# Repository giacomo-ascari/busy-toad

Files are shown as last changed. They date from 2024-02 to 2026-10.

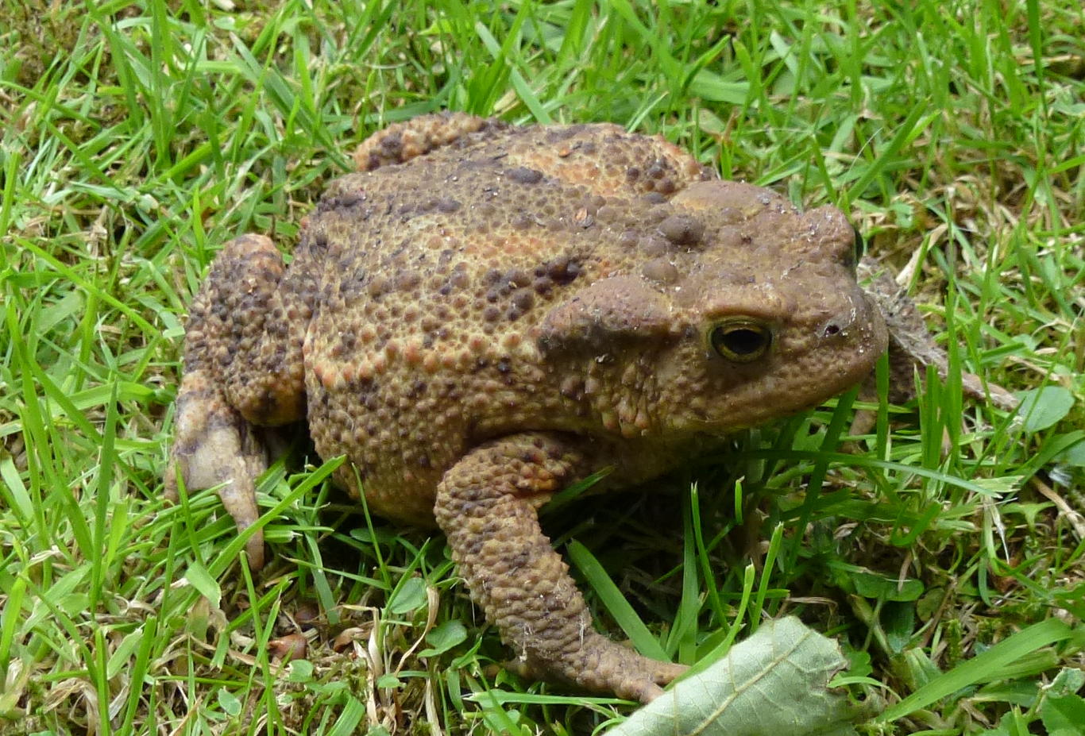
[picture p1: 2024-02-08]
images/ref.jpg

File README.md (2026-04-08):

# busy-toad

## Intro

Evolution of the digital pedal geekyToad. This page is a list of features/hardware that I would like to implement.

## System

### I/O

- Two audio instr/line inputs as TRS Jack (differential or single-ended)
- Two audio instr/line outputs as TRS Jack (differential or single-ended)
- One stereo output for headphones, hardwired to the two outputs
- OLED display, power LED, some non-assigned (yet) LEDs
- A lot of buttons and One rotary encoder with push buttono
- Volume knob for heaphones
- Four analog inputs as TRS Jack (e.g. expression pedals and stomp buttons)
- USB C device for power and FS data transfer

### Features

- Effect chains
- Programmable expression inputs as dynamic controls of effects
- Drum machine (synth + samples)
- Chromatic tuner
- Mixing matrix for effect chains and drum machine
- Simple cab emulation

## Hardware

### DSP MCU - STM32H750VBT6

- LQFP100 14x14x1.4mm
- ARM Cortex-M7, 480MHz, FPU, 128kB flash, 1024kB RAM
- Gotta use the CMSIS-DSP library!!!
- [mouser link](https://www.mouser.dk/ProductDetail/STMicroelectronics/STM32H750VBT6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)

### UI MCU - STM32H523CEU6

- UFQFPN-48
- ARM Cortex M33, 250MHz, FPU, 512kB flash, 272kB RAM
- [mouser link](https://eu.mouser.com/ProductDetail/STMicroelectronics/STM32H523CEU6?qs=ZcfC38r4Pot%2FWfU8ati%252BDA%3D%3D)

### CODEC - ADAU1916

- [analog devices link](https://www.analog.com/media/en/technical-documentation/data-sheets/adau1961.pdf)

Honorable mentions:

- cs4272, [cirrus logic link](https://www.cirrus.com/products/cs4272/), used in some focusrite scarlet interfaces [apparently](https://khronscave.blogspot.com/2019/10/55-focusrite-scarlett-2i2-teardown.html)
- E.D.'s favorite: tlv320aic3104-21
- daisy seed's: pcm3060 [ti link](https://www.ti.com/product/PCM3060#features)
- PCM1863 [ti link](https://www.ti.com/product/PCM1863) 

### FLASH - W25Q512JV

- w25q512jveim (still on the table!)
- the quad spi interface with the mcu needs a lot of pins :/

### DISPLAY - 3.83" OLED

- 3.83" OLED module, 320x132, 4-wire SPI, 16 level grayscale
- looks really interesting and promising, especially for the grayscale control (could have controllable brightness and such)
- framerate unknow, but still probably better than normal lcd displays
- [buydisplay link](https://www.buydisplay.com/catalog/product/view/id/1847/s/arduino-raspberry-pi-3-83-inch-oled-module-320x132-spi-16-level-grayscale/)
- ALTERNATIVE: ILI9341 SPI LCD display (the usual basically)

## Various notes

- probably not using this case: [1590XX](https://www.mouser.dk/ProductDetail/Hammond-Manufacturing/1590XXPR?qs=kWu6FN6bAPyKJolG0UKSGg%3D%3D)
- STM32 Cube IDE because yes.
- Debugging is done with cortex 4-wire-jtag/swd 10 pin connection.
- For the Eq: Linkwitz–Riley filters
- Denoising for 5v: either LDOs, or a lot of filtering (pi filter and ferrite beads like BLM21PG102SH1D)
- circuitry for codec I/O:
  - INA116: instrumentation amplifier with extremely low input bias
  - INA105 and 106: differential amplifiers with unit and fixed gain
  - INA1620: beast, dual differential signals amp
  - INA321 and 2321: instrumentation amplifiers, also dual channel
  - MCP6001/1R/1U/2/4: low power opamp used in gt
  - Quad Analog Switch/ Multiplexer/Demultiplexer MC74HC4066A
- For the switching circuitry (might not be needed with ADAU1961!)
  - MC74HC4066A (same as the focusrite, but apparently a little bit noisy)
  - TS5A3157
  - DG409 / DG410
  - MAX4617 (chatgpt likes this)
  - ADG736 (I like this one!) / ADG734 / ADG1606
  - TS5A3157
  - MAX14689
- Notes for capacitors
  - 20% is tolerable for PDB, but 10% is better
  - DC rating at least double the maximum applied voltage
  - increase cap value to account for derating and tolerance
  - for audio, avoid class 2 ceramics in signal path.
  - use NP0/C0G insted, unfortunately only available as small value caps (10nF or less)
- Available in lab
  - CA3140 (opamp)
  - MCP6294 (quad opamp)
  - MCP602 (dual op amp)
  - LM358 (dual op amp)
  - LM386N (audio amp)
  - AD623ANZ (opamp dif amp)
  - AD620ANZ (opamp dif amp)
- Expression pedals are hard man [...](https://missionengineering.com/understanding-expression-pedals/)
- I'm extremely dubious about the feasibility of the 48v phantom power for condenser microphones. A solution can be just buying an external mic pre-amp.
- [cool colors, i like them](https://coolors.co/30bced-303036-fffaff-fc5130-050401)
- [Differences-between-Mic-Line-and-Instrument-level](https://support.focusrite.com/hc/en-gb/articles/115004171025-Differences-between-Mic-Line-and-Instrument-level)

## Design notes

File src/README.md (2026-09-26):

# Source code

## Organization

The development relies on a CubeMX + cmake toolchain. The code for the primary MCU is `bt_h750`, while the secondary's one is found in `bt_h523`.

## How to stuff

### Flash #1

After having built the `.elf` file all is left to do is to flash it.

On terminal 1:

- `st-info --probe` giusto per vedere se legge la roba
- `st-util` per lanciare partire il server gdb. importante!

On terminal 2:

- `gdb-multiarch PATH_TO_ELF`
- `(gdb) target extended-remote localhost:4242`
- `(gdb) load`
- `(gdb) continue`

### Flash #2

`STM32_Programmer_CLI -c port=SWD mode=UR reset=HWrst -w build/Debug/bt_h750.elf -v -rst`

### Flash #3

Trust VSCode.

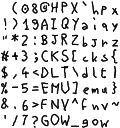
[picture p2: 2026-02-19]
images/font/raw_font_10x16.png

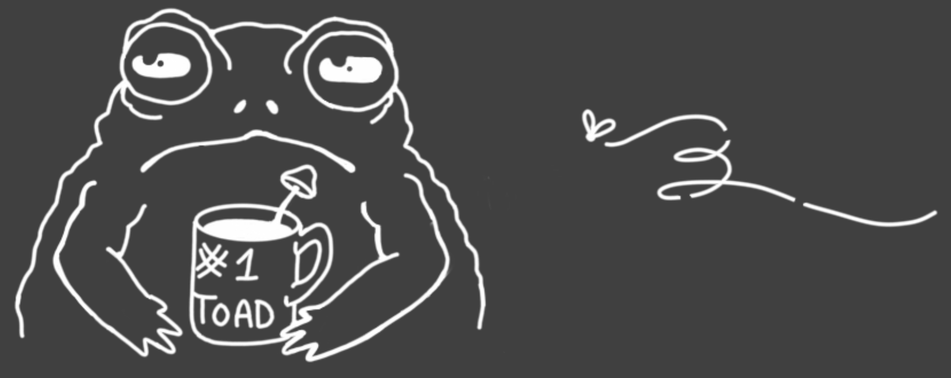
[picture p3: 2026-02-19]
images/toadddd.png

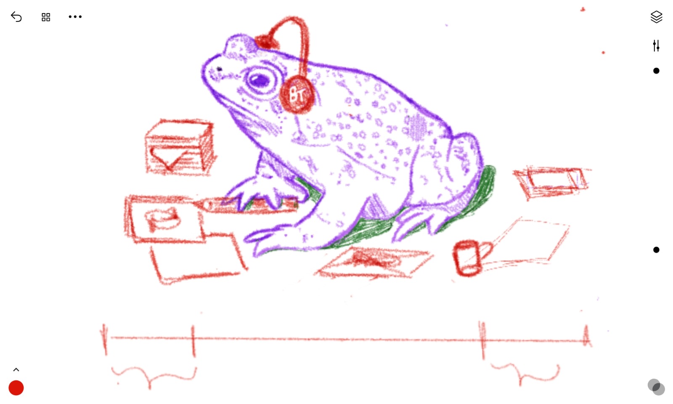
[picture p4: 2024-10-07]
images/g.jpg

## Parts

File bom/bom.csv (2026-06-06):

Reference | Qty | Value | Exclude from BOM | Footprint | Description
C1,C3,C5,C7,C12 | 5 | 100n |  | Capacitor_SMD:C_0603_1608Metric_Pad1.08x0.95mm_HandSolder | POWERSUPPLY
C2,C4,C6,C11 | 4 | 10u |  | Capacitor_SMD:C_0805_2012Metric_Pad1.18x1.45mm_HandSolder | POWERSUPPLY
C8,C13 | 2 | 1u |  | Capacitor_SMD:C_0603_1608Metric_Pad1.08x0.95mm_HandSolder | POWERSUPPLY
C9,C53,C58,C67,C69,C71,C72 | 7 | 2.2u |  | Capacitor_SMD:C_0603_1608Metric_Pad1.08x0.95mm_HandSolder | DPD
C10,C43,C44,C46,C47,C48,C49,C50,C51,C52,C54,C55,C56,C57,C59,C60,C61,C62,C64,C66,C68,C70 | 22 | 100n |  | Capacitor_SMD:C_0603_1608Metric_Pad1.08x0.95mm_HandSolder | DPD
C14 | 1 | 2.2u |  | Capacitor_SMD:C_0603_1608Metric_Pad1.08x0.95mm_HandSolder | APD
C15,C19,C22,C23,C24,C33,C34,C36,C39,C41,C80,C88 | 12 | 100n |  | Capacitor_SMD:C_0603_1608Metric_Pad1.08x0.95mm_HandSolder | APD
C16,C18,C20,C21 | 4 | 22u |  | Capacitor_SMD:C_0805_2012Metric_Pad1.18x1.45mm_HandSolder | APD
C17,C26,C27,C29,C30,C31,C79,C87 | 8 | 10u |  | Capacitor_SMD:C_0805_2012Metric_Pad1.18x1.45mm_HandSolder | APD
C25,C28,C32,C35,C37,C38,C40,C42 | 8 | 1u |  | Capacitor_SMD:C_0603_1608Metric_Pad1.08x0.95mm_HandSolder | APD
C45 | 1 | 10u |  | Capacitor_SMD:C_0805_2012Metric_Pad1.18x1.45mm_HandSolder | DPD
C63,C65 | 2 | 1u |  | Capacitor_SMD:C_0603_1608Metric_Pad1.08x0.95mm_HandSolder | DPD
C73,C76,C78,C83,C85,C90,C93,C96 | 8 | 470p |  | Capacitor_SMD:C_0603_1608Metric_Pad1.08x0.95mm_HandSolder | AUDIO
C74,C77,C81,C84,C86,C92,C94,C98 | 8 | 10u |  | Capacitor_SMD:C_0805_2012Metric_Pad1.18x1.45mm_HandSolder | AUDIO
C75,C82,C89,C95 | 4 | 2.7n |  | Capacitor_SMD:C_0603_1608Metric_Pad1.08x0.95mm_HandSolder | AUDIO
C91,C97 | 2 | 10n |  | Capacitor_SMD:C_0603_1608Metric_Pad1.08x0.95mm_HandSolder | AUDIO
D1,D2 | 2 | B5819W |  | library:SOD3716X125N | 40V 1A 600mV @ 1A SOD-123 Schottky Barrier Diodes (SBD)
D3,D5,D7,D9,D11,D13,D15,D17,D18 | 9 | LED |  | LED_SMD:LED_0603_1608Metric_Pad1.05x0.95mm_HandSolder | Light emitting diode
D4,D6,D8,D10,D12,D14,D16 | 7 | LED |  | LED_THT:LED_D3.0mm | Light emitting diode
IC1 | 1 | LV3842XDBVR |  | library:SOT95P280X145-6N | Switching Voltage Regulators 4-V to 36-V, 600-mA synchronous step-down converter 6-SOT-23 -40 to 125
IC2 | 1 | CS4282P |  | library:QFN40P600X600X80-49N-D | High performance two-channel codec Differential analog architecture High-resolution 32-bit digital architecture Low-latency digital filters and digital volume control Current-mode output for optimal dynamic range into application-specific output buffer PLL supports range of external system-clock references Sample timing alignment across multiple devices Synchronized control of external preamplifier gain Audio serial port (ASP) sample rates up to 768 kHz I2S, left-justified, and TDM data f
IC3 | 1 | TAD5242IRGER |  | library:TAD5242IRGER | Audio D/A Converter ICs Hardware-control stereo audio DAC with 120dB dynamic range, and headphone and line driver
IC4 | 1 | STM32H750VBT6 |  | library:QFP50P1600X1600X160-100N
IC5 | 1 | STM32H523CET6 |  | library:QFP50P900X900X160-48N | Arm Cortex-M33 32-bit MCU + TrustZone + FPU, 375 DMIPS, 250 MHz, 512-Kbyte flash, 272-Kbyte RAM
J2 | 1 | Barrel_Jack_Switch |  | library:694106301002_1 | DC Barrel Jack with an internal switch
J7 | 1 | USB_C_Receptacle_USB2.0_16P |  | Connector_USB:USB_C_Receptacle_GCT_USB4105-xx-A_16P_TopMnt_Horizontal | USB 2.0-only 16P Type-C Receptacle connector
J14 | 1 | Micro_SD_Card_Det2 |  | Connector_Card:microSD_HC_Molex_104031-0811 | Micro SD Card Socket with two card detection pins
J15,J16,J17,J18 | 4 | ReanNYS216G |  | library:NYS-216G
L1 | 1 | 18uH 1.5A |  | library:SRR6040A180M | Inductor with iron core
R1 | 1 | 100k |  | Resistor_SMD:R_0603_1608Metric_Pad0.98x0.95mm_HandSolder | Resistor
R2,R3 | 2 | 47k |  | Resistor_SMD:R_0603_1608Metric_Pad0.98x0.95mm_HandSolder | Resistor
R4,R5 | 2 | 22 |  | Resistor_SMD:R_0603_1608Metric_Pad0.98x0.95mm_HandSolder
R6,R10,R11,R12,R13,R14,R15,R16,R24,R25,R26,R27,R28,R29,R30,R31,R32,R33,R34,R35,R36,R37,R40,R44,R46,R52,R54,R59,R61,R65,R67 | 31 | 10k |  | Resistor_SMD:R_0603_1608Metric_Pad0.98x0.95mm_HandSolder
R7 | 1 | 4k7 |  | Resistor_SMD:R_0603_1608Metric_Pad0.98x0.95mm_HandSolder
R8,R9 | 2 | 5k1 |  | Resistor_SMD:R_0603_1608Metric_Pad0.98x0.95mm_HandSolder
R17,R18,R19,R20,R21,R22,R23 | 7 | 680/510 |  | Resistor_SMD:R_0603_1608Metric_Pad0.98x0.95mm_HandSolder
R38,R39 | 2 | 680 |  | Resistor_SMD:R_0603_1608Metric_Pad0.98x0.95mm_HandSolder
R41,R45,R49,R53,R57,R60,R63,R66 | 8 | 634 |  | Resistor_SMD:R_0603_1608Metric_Pad0.98x0.95mm_HandSolder
R42,R47,R50,R55,R58,R62,R64,R68 | 8 | 91 |  | Resistor_SMD:R_0603_1608Metric_Pad0.98x0.95mm_HandSolder
R43,R48,R51,R56 | 4 | 470 |  | Resistor_SMD:R_0603_1608Metric_Pad0.98x0.95mm_HandSolder
RV1,RV2,RV3 | 3 | CG0402MLU-12G |  | library:VARC1005X41N | ESD Suppressors / TVS Diodes CHIP GUARD 12VOLT
RV4 | 1 | R_Potentiometer |  | Potentiometer_THT:Potentiometer_Alpha_RD901F-40-00D_Single_Vertical_CircularHoles | Potentiometer
SW1 | 1 | RotaryEncoder_Switch |  | Rotary_Encoder:RotaryEncoder_Alps_EC11E-Switch_Vertical_H20mm_CircularMountingHoles | Rotary encoder, dual channel, incremental quadrate outputs, with switch
SW2,SW3,SW4,SW5,SW6,SW7,SW8,SW9,SW10,SW11 | 10 | SW_Push |  | Button_Switch_THT:SW_TH_Tactile_Omron_B3F-102x
U1,U2 | 2 | TLV76133DCY |  | Package_TO_SOT_SMD:SOT-223-3_TabPin2 | 3.3V, 1A, Low Noise, High-PSRR LDO Regulator, 2.5V...16V input, SOT-223
U3,U4 | 2 | MCP6004 |  | Package_SO:TSSOP-14_4.4x5mm_P0.65mm

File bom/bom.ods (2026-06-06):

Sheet: bom_rev_A
Reference | Qty | Value | Footprint | Description
C1,C3,C5,C7,C12 | 5 | 100n | Capacitor_SMD:C_0603_1608Metric_Pad1.08x0.95mm_HandSolder | POWERSUPPLY
C2,C4,C6,C11 | 4 | 10u | Capacitor_SMD:C_0805_2012Metric_Pad1.18x1.45mm_HandSolder | POWERSUPPLY
C8,C13 | 2 | 1u | Capacitor_SMD:C_0603_1608Metric_Pad1.08x0.95mm_HandSolder | POWERSUPPLY
C9,C38,C42,C52,C54,C56 | 6 | 2.2u | Capacitor_SMD:C_0603_1608Metric_Pad1.08x0.95mm_HandSolder | DPD
C10,C22,C25,C28,C29,C31,C32,C33,C34,C35,C36,C37,C39,C40,C41,C43,C44,C45,C46,C47,C49,C51,C53,C55 | 24 | 100n | Capacitor_SMD:C_0603_1608Metric_Pad1.08x0.95mm_HandSolder | DPD
C14 | 1 | 2.2u | Capacitor_SMD:C_0603_1608Metric_Pad1.08x0.95mm_HandSolder | APD
C15,C18,C21,C65,C74 | 5 | 100n | Capacitor_SMD:C_0603_1608Metric_Pad1.08x0.95mm_HandSolder | APD
C16,C19,C64,C73 | 4 | 10u | Capacitor_SMD:C_0805_2012Metric_Pad1.18x1.45mm_HandSolder | APD
C17,C20 | 2 | 1u | Capacitor_SMD:C_0603_1608Metric_Pad1.08x0.95mm_HandSolder | APD
C23,C24,C30 | 3 | 10u | Capacitor_SMD:C_0805_2012Metric_Pad1.18x1.45mm_HandSolder | DPD
C26,C58,C62,C66,C70,C72,C78,C80,C84 | 9 | 10u | Capacitor_SMD:C_0805_2012Metric_Pad1.18x1.45mm_HandSolder | AUDIO
C27 | 1 | 100n | Capacitor_SMD:C_0603_1608Metric_Pad1.08x0.95mm_HandSolder | AUDIO
C48,C50 | 2 | 1u | Capacitor_SMD:C_0603_1608Metric_Pad1.08x0.95mm_HandSolder | DPD
C57,C61,C63,C69,C71,C76,C79,C82 | 8 | 470p | Capacitor_SMD:C_0603_1608Metric_Pad1.08x0.95mm_HandSolder | AUDIO
C59,C67,C75,C81 | 4 | 2.7n | Capacitor_SMD:C_0603_1608Metric_Pad1.08x0.95mm_HandSolder | AUDIO
C60,C68,C77,C83 | 4 | 10n | Capacitor_SMD:C_0603_1608Metric_Pad1.08x0.95mm_HandSolder | AUDIO
D1,D2 | 2 | B5819W | library:SOD3716X125N | 40V 1A 600mV @ 1A SOD-123 Schottky Barrier Diodes (SBD)
D3,D5,D7,D9,D11,D13,D15,D17,D18 | 9 | LED | LED_SMD:LED_0603_1608Metric_Pad1.05x0.95mm_HandSolder | Light emitting diode
D4,D6,D8,D10,D12,D14,D16 | 7 | LED | LED_THT:LED_D3.0mm | Light emitting diode
H1,H2,H3,H4,H5,H6 | 6 | MountingHole_Pad | MountingHole:MountingHole_3.2mm_M3_ISO14580_Pad | Mounting Hole with connection
IC1 | 1 | LV3842XDBVR | library:SOT95P280X145-6N | Switching Voltage Regulators 4-V to 36-V, 600-mA synchronous step-down converter 6-SOT-23 -40 to 125
IC2 | 1 | ADAU1961WBCPZ-R7 | library:QFN50P500X500X100-33N-D | General Purpose Audio Codec 2ADC / 2DAC Ch Automotive 32-Pin LFCSP EP T/R
IC3 | 1 | STM32H750VBT6 | library:QFP50P1600X1600X160-100N
IC4 | 1 | STM32H523CEU6 | library:QFN50P700X700X60-49N-D
IC5 | 1 | W25Q512JVEIM | library:SON127P800X600X80-9N-D
J1 | 1 | Conn_01x02 | Connector_PinHeader_2.54mm:PinHeader_1x02_P2.54mm_Vertical | Generic connector, single row, 01x02, script generated (kicad-library-utils/schlib/autogen/connector/)
J2 | 1 | Barrel_Jack_Switch | library:694106301002_1 | DC Barrel Jack with an internal switch
J3 | 1 | Conn_01x01 | Connector_PinHeader_2.54mm:PinHeader_1x01_P2.54mm_Vertical | Generic connector, single row, 01x01, script generated (kicad-library-utils/schlib/autogen/connector/)
J4,J5,J7,J9,J10,J11 | 6 | Conn_01x03 | Connector_JST:JST_PH_B3B-PH-K_1x03_P2.00mm_Vertical | Generic connector, single row, 01x03, script generated (kicad-library-utils/schlib/autogen/connector/)
J6 | 1 | ER-OLEDM0383-1-SPI_Conn_01x10 | library:ER-OLEDM0383-1-SPI | Generic connector, single row, 01x10, script generated (kicad-library-utils/schlib/autogen/connector/)
J8 | 1 | USB_C_Receptacle_USB2.0_16P | Connector_USB:USB_C_Receptacle_GCT_USB4105-xx-A_16P_TopMnt_Horizontal | USB 2.0-only 16P Type-C Receptacle connector
J12,J13,J14 | 3 | Conn_01x05 | Connector_JST:JST_PH_B5B-PH-K_1x05_P2.00mm_Vertical | Generic connector, single row, 01x05, script generated (kicad-library-utils/schlib/autogen/connector/)
J15,J16,J17,J18 | 4 | ReanNYS216G | library:NYS-216G
JP1 | 1 | SJ+ | Jumper:SolderJumper-3_P1.3mm_Open_Pad1.0x1.5mm | Solder Jumper, 3-pole, open
JP2 | 1 | SJ- | Jumper:SolderJumper-3_P1.3mm_Open_Pad1.0x1.5mm | Solder Jumper, 3-pole, open
L1 | 1 | 18uH 1.5A | library:SRR6040A180M | Inductor with iron core
R1 | 1 | 100k | Resistor_SMD:R_0603_1608Metric_Pad0.98x0.95mm_HandSolder | Resistor
R2,R3 | 2 | 47k | Resistor_SMD:R_0603_1608Metric_Pad0.98x0.95mm_HandSolder | Resistor
R4 | 1 | 49.9 | Resistor_SMD:R_0603_1608Metric_Pad0.98x0.95mm_HandSolder | Resistor
R5,R6,R7,R8 | 4 | 0 | Resistor_SMD:R_0603_1608Metric_Pad0.98x0.95mm_HandSolder | Resistor
R9,R11,R12,R15,R16,R17,R18,R19,R27,R28,R29,R30,R31,R32,R33,R34,R35,R36,R37,R38,R39,R40,R46,R48,R54,R56,R61,R63,R67,R69 | 30 | 10k | Resistor_SMD:R_0603_1608Metric_Pad0.98x0.95mm_HandSolder
R10 | 1 | 4k7 | Resistor_SMD:R_0603_1608Metric_Pad0.98x0.95mm_HandSolder
R13,R14 | 2 | 5k1 | Resistor_SMD:R_0603_1608Metric_Pad0.98x0.95mm_HandSolder
R20,R21,R22,R23,R24,R25,R26 | 7 | 680/510 | Resistor_SMD:R_0603_1608Metric_Pad0.98x0.95mm_HandSolder
R41,R42 | 2 | 680 | Resistor_SMD:R_0603_1608Metric_Pad0.98x0.95mm_HandSolder
R43,R47,R51,R55,R59,R62,R65,R68 | 8 | 634 | Resistor_SMD:R_0603_1608Metric_Pad0.98x0.95mm_HandSolder
R44,R49,R52,R57,R60,R64,R66,R70 | 8 | 91 | Resistor_SMD:R_0603_1608Metric_Pad0.98x0.95mm_HandSolder
R45,R50,R53,R58 | 4 | 470 | Resistor_SMD:R_0603_1608Metric_Pad0.98x0.95mm_HandSolder
RV1,RV2,RV3 | 3 | CG0402MLU-12G | library:VARC1005X41N | ESD Suppressors / TVS Diodes CHIP GUARD 12VOLT
RV4 | 1 | R_Potentiometer | Potentiometer_THT:Potentiometer_Alpha_RD901F-40-00D_Single_Vertical_CircularHoles
SW1 | 1 | RotaryEncoder_Switch | Rotary_Encoder:RotaryEncoder_Alps_EC11E-Switch_Vertical_H20mm_CircularMountingHoles | Rotary encoder, dual channel, incremental quadrate outputs, with switch
SW2,SW3,SW4,SW5,SW6,SW7,SW8,SW9,SW10,SW11 | 10 | SW_Push | Button_Switch_THT:SW_TH_Tactile_Omron_B3F-102x
TP1,TP2,TP3,TP4 | 4 | TestPoint | TestPoint:TestPoint_Pad_D1.0mm | test point
U1,U2 | 2 | TLV76133DCY | Package_TO_SOT_SMD:SOT-223-3_TabPin2 | 3.3V, 1A, Low Noise, High-PSRR LDO Regulator, 2.5V...16V input, SOT-223
U3,U4 | 2 | MCP6004 | Package_SO:TSSOP-14_4.4x5mm_P0.65mm

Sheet: bom_rev_B
Reference | Qty | Value | Footprint | Description
C1,C3,C5,C7,C12 | 5 | 100n | Capacitor_SMD:C_0603_1608Metric_Pad1.08x0.95mm_HandSolder | POWERSUPPLY
C2,C4,C6,C11 | 4 | 10u | Capacitor_SMD:C_0805_2012Metric_Pad1.18x1.45mm_HandSolder | POWERSUPPLY
C8,C15 | 2 | 1u | Capacitor_SMD:C_0603_1608Metric_Pad1.08x0.95mm_HandSolder | POWERSUPPLY
C9,C60,C65,C74,C76,C78,C79 | 7 | 2.2u | Capacitor_SMD:C_0603_1608Metric_Pad1.08x0.95mm_HandSolder | DPD
C10,C50,C51,C53,C54,C55,C56,C57,C58,C59,C61,C62,C63,C64,C66,C67,C68,C69,C71,C73,C75,C77 | 22 | 100n | Capacitor_SMD:C_0603_1608Metric_Pad1.08x0.95mm_HandSolder | DPD
C13,C14,C70,C72 | 4 | 1u | Capacitor_SMD:C_0603_1608Metric_Pad1.08x0.95mm_HandSolder | DPD
C16 | 1 | 2.2u | Capacitor_SMD:C_0603_1608Metric_Pad1.08x0.95mm_HandSolder | APD
C17,C22,C23,C25,C28,C29,C30,C38,C39,C47,C48,C88,C97 | 13 | 100n | Capacitor_SMD:C_0603_1608Metric_Pad1.08x0.95mm_HandSolder | APD
C18,C24,C26,C27 | 4 | 22u | Capacitor_SMD:C_0805_2012Metric_Pad1.18x1.45mm_HandSolder | APD
C19,C20,C31,C33,C34,C35,C37,C40,C41,C42,C46,C49 | 12 | 1u | Capacitor_SMD:C_0603_1608Metric_Pad1.08x0.95mm_HandSolder | APD
C21,C32,C36,C43,C87,C96 | 6 | 10u | Capacitor_SMD:C_0805_2012Metric_Pad1.18x1.45mm_HandSolder | APD
C44,C45 | 2 | 47u | Capacitor_SMD:C_0805_2012Metric_Pad1.18x1.45mm_HandSolder | APD
C52 | 1 | 10u | Capacitor_SMD:C_0805_2012Metric_Pad1.18x1.45mm_HandSolder | DPD
C80,C84,C86,C92,C94,C99,C102,C105 | 8 | 470p | Capacitor_SMD:C_0603_1608Metric_Pad1.08x0.95mm_HandSolder | AUDIO
C81,C85,C89,C93,C95,C101,C103,C107 | 8 | 10u | Capacitor_SMD:C_0805_2012Metric_Pad1.18x1.45mm_HandSolder | AUDIO
C82,C90,C98,C104 | 4 | 2.7n | Capacitor_SMD:C_0603_1608Metric_Pad1.08x0.95mm_HandSolder | AUDIO
C83,C91,C100,C106 | 4 | 10n | Capacitor_SMD:C_0603_1608Metric_Pad1.08x0.95mm_HandSolder | AUDIO
D1,D2 | 2 | B5819W | library:SOD3716X125N | 40V 1A 600mV @ 1A SOD-123 Schottky Barrier Diodes (SBD)
D3,D5,D7,D9,D11,D13,D15,D17,D18 | 9 | LED | LED_SMD:LED_0603_1608Metric_Pad1.05x0.95mm_HandSolder | Light emitting diode
D4,D6,D8,D10,D12,D14,D16 | 7 | LED | LED_THT:LED_D3.0mm | Light emitting diode
IC1 | 1 | LV3842XDBVR | library:SOT95P280X145-6N | Switching Voltage Regulators 4-V to 36-V, 600-mA synchronous step-down converter 6-SOT-23 -40 to 125
IC2 | 1 | TLV320DAC3203IRGER | library:QFN50P400X400X100-25N-D | Interface - CODECs Ultra Low Pwr Stereo Audio Codec
IC3 | 1 | CS4282P | library:QFN40P600X600X80-49N-D
IC4 | 1 | STM32H750VBT6 | library:QFP50P1600X1600X160-100N
IC5 | 1 | STM32H523CET6 | library:QFP50P900X900X160-48N | Arm Cortex-M33 32-bit MCU + TrustZone + FPU, 375 DMIPS, 250 MHz, 512-Kbyte flash, 272-Kbyte RAM
J2 | 1 | Barrel_Jack_Switch | library:694106301002_1 | DC Barrel Jack with an internal switch
J7 | 1 | USB_C_Receptacle_USB2.0_16P | Connector_USB:USB_C_Receptacle_GCT_USB4105-xx-A_16P_TopMnt_Horizontal | USB 2.0-only 16P Type-C Receptacle connector
J14 | 1 | Micro_SD_Card_Det2 | Connector_Card:microSD_HC_Molex_104031-0811 | Micro SD Card Socket with two card detection pins
J15,J16,J17,J18 | 4 | ReanNYS216G | library:NYS-216G
L1 | 1 | 18uH 1.5A | library:SRR6040A180M | Inductor with iron core
R1 | 1 | 100k | Resistor_SMD:R_0603_1608Metric_Pad0.98x0.95mm_HandSolder | Resistor
R2,R3 | 2 | 47k | Resistor_SMD:R_0603_1608Metric_Pad0.98x0.95mm_HandSolder | Resistor
R4,R8,R9,R10,R11,R12,R13,R14,R22,R23,R24,R25,R26,R27,R28,R29,R30,R31,R32,R33,R34,R35,R38,R42,R44,R50,R52,R57,R59,R63,R65 | 31 | 10k | Resistor_SMD:R_0603_1608Metric_Pad0.98x0.95mm_HandSolder
R5 | 1 | 4k7 | Resistor_SMD:R_0603_1608Metric_Pad0.98x0.95mm_HandSolder
R6,R7 | 2 | 5k1 | Resistor_SMD:R_0603_1608Metric_Pad0.98x0.95mm_HandSolder
R15,R16,R17,R18,R19,R20,R21 | 7 | 680/510 | Resistor_SMD:R_0603_1608Metric_Pad0.98x0.95mm_HandSolder
R36,R37 | 2 | 680 | Resistor_SMD:R_0603_1608Metric_Pad0.98x0.95mm_HandSolder
R39,R43,R47,R51,R55,R58,R61,R64 | 8 | 634 | Resistor_SMD:R_0603_1608Metric_Pad0.98x0.95mm_HandSolder
R40,R45,R48,R53,R56,R60,R62,R66 | 8 | 91 | Resistor_SMD:R_0603_1608Metric_Pad0.98x0.95mm_HandSolder
R41,R46,R49,R54 | 4 | 470 | Resistor_SMD:R_0603_1608Metric_Pad0.98x0.95mm_HandSolder
RV1,RV2,RV3 | 3 | CG0402MLU-12G | library:VARC1005X41N | ESD Suppressors / TVS Diodes CHIP GUARD 12VOLT
RV4 | 1 | R_Potentiometer | Potentiometer_THT:Potentiometer_Alpha_RD901F-40-00D_Single_Vertical_CircularHoles | Potentiometer
SW1 | 1 | RotaryEncoder_Switch | Rotary_Encoder:RotaryEncoder_Alps_EC11E-Switch_Vertical_H20mm_CircularMountingHoles | Rotary encoder, dual channel, incremental quadrate outputs, with switch
SW2,SW3,SW4,SW5,SW6,SW7,SW8,SW9,SW10,SW11 | 10 | SW_Push | Button_Switch_THT:SW_TH_Tactile_Omron_B3F-102x
U1,U3 | 2 | TLV76133DCY | Package_TO_SOT_SMD:SOT-223-3_TabPin2 | 3.3V, 1A, Low Noise, High-PSRR LDO Regulator, 2.5V...16V input, SOT-223
U2 | 1 | TPS7A2018PDBV | Package_TO_SOT_SMD:SOT-23-5 | 300 mA Low Dropout Voltage Regulator, Fixed Output, 1.6..6.0Vin, Low-Noise (7μV RMS), 6.5μA IQ LDO, SOT-23
U4,U5 | 2 | MCP6004 | Package_SO:TSSOP-14_4.4x5mm_P0.65mm

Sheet: bom_rev_B_2
Reference | Qty | Value | Footprint | Description
C1,C3,C5,C7,C12 | 5 | 100n | Capacitor_SMD:C_0603_1608Metric_Pad1.08x0.95mm_HandSolder | POWERSUPPLY
C2,C4,C6,C11 | 4 | 10u | Capacitor_SMD:C_0805_2012Metric_Pad1.18x1.45mm_HandSolder | POWERSUPPLY
C8,C13 | 2 | 1u | Capacitor_SMD:C_0603_1608Metric_Pad1.08x0.95mm_HandSolder | POWERSUPPLY
C9,C53,C58,C67,C69,C71,C72 | 7 | 2.2u | Capacitor_SMD:C_0603_1608Metric_Pad1.08x0.95mm_HandSolder | DPD
C10,C43,C44,C46,C47,C48,C49,C50,C51,C52,C54,C55,C56,C57,C59,C60,C61,C62,C64,C66,C68,C70 | 22 | 100n | Capacitor_SMD:C_0603_1608Metric_Pad1.08x0.95mm_HandSolder | DPD
C14 | 1 | 2.2u | Capacitor_SMD:C_0603_1608Metric_Pad1.08x0.95mm_HandSolder | APD
C15,C19,C22,C23,C24,C33,C34,C36,C39,C41,C80,C88 | 12 | 100n | Capacitor_SMD:C_0603_1608Metric_Pad1.08x0.95mm_HandSolder | APD
C16,C18,C20,C21 | 4 | 22u | Capacitor_SMD:C_0805_2012Metric_Pad1.18x1.45mm_HandSolder | APD
C17,C26,C27,C29,C30,C31,C79,C87 | 8 | 10u | Capacitor_SMD:C_0805_2012Metric_Pad1.18x1.45mm_HandSolder | APD
C25,C28,C32,C35,C37,C38,C40,C42 | 8 | 1u | Capacitor_SMD:C_0603_1608Metric_Pad1.08x0.95mm_HandSolder | APD
C45 | 1 | 10u | Capacitor_SMD:C_0805_2012Metric_Pad1.18x1.45mm_HandSolder | DPD
C63,C65 | 2 | 1u | Capacitor_SMD:C_0603_1608Metric_Pad1.08x0.95mm_HandSolder | DPD
C73,C76,C78,C83,C85,C90,C93,C96 | 8 | 470p | Capacitor_SMD:C_0603_1608Metric_Pad1.08x0.95mm_HandSolder | AUDIO
C74,C77,C81,C84,C86,C92,C94,C98 | 8 | 10u | Capacitor_SMD:C_0805_2012Metric_Pad1.18x1.45mm_HandSolder | AUDIO
C75,C82,C89,C95 | 4 | 2.7n | Capacitor_SMD:C_0603_1608Metric_Pad1.08x0.95mm_HandSolder | AUDIO
C91,C97 | 2 | 10n | Capacitor_SMD:C_0603_1608Metric_Pad1.08x0.95mm_HandSolder | AUDIO
D1,D2 | 2 | B5819W | library:SOD3716X125N | 40V 1A 600mV @ 1A SOD-123 Schottky Barrier Diodes (SBD)
D3,D5,D7,D9,D11,D13,D15,D17,D18 | 9 | LED | LED_SMD:LED_0603_1608Metric_Pad1.05x0.95mm_HandSolder | Light emitting diode
D4,D6,D8,D10,D12,D14,D16 | 7 | LED | LED_THT:LED_D3.0mm | Light emitting diode
IC1 | 1 | LV3842XDBVR | library:SOT95P280X145-6N | Switching Voltage Regulators 4-V to 36-V, 600-mA synchronous step-down converter 6-SOT-23 -40 to 125
IC2 | 1 | CS4282P | library:QFN40P600X600X80-49N-D | High performance two-channel codec Differential analog architecture High-resolution 32-bit digital architecture Low-latency digital filters and digital volume control Current-mode output for optimal dynamic range into application-specific output buffer PLL supports range of external system-clock references Sample timing alignment across multiple devices Synchronized control of external preamplifier gain Audio serial port (ASP) sample rates up to 768 kHz I2S, left-justified, and TDM data f
IC3 | 1 | TAD5242IRGER | library:TAD5242IRGER | Audio D/A Converter ICs Hardware-control stereo audio DAC with 120dB dynamic range, and headphone and line driver
IC4 | 1 | STM32H750VBT6 | library:QFP50P1600X1600X160-100N
IC5 | 1 | STM32H523CET6 | library:QFP50P900X900X160-48N | Arm Cortex-M33 32-bit MCU + TrustZone + FPU, 375 DMIPS, 250 MHz, 512-Kbyte flash, 272-Kbyte RAM
J2 | 1 | Barrel_Jack_Switch | library:694106301002_1 | DC Barrel Jack with an internal switch
J7 | 1 | USB_C_Receptacle_USB2.0_16P | Connector_USB:USB_C_Receptacle_GCT_USB4105-xx-A_16P_TopMnt_Horizontal | USB 2.0-only 16P Type-C Receptacle connector
J14 | 1 | Micro_SD_Card_Det2 | Connector_Card:microSD_HC_Molex_104031-0811 | Micro SD Card Socket with two card detection pins
J15,J16,J17,J18 | 4 | ReanNYS216G | library:NYS-216G
L1 | 1 | 18uH 1.5A | library:SRR6040A180M | Inductor with iron core
R1 | 1 | 100k | Resistor_SMD:R_0603_1608Metric_Pad0.98x0.95mm_HandSolder | Resistor
R2,R3 | 2 | 47k | Resistor_SMD:R_0603_1608Metric_Pad0.98x0.95mm_HandSolder | Resistor
R4,R5 | 2 | 22 | Resistor_SMD:R_0603_1608Metric_Pad0.98x0.95mm_HandSolder
R6,R10,R11,R12,R13,R14,R15,R16,R24,R25,R26,R27,R28,R29,R30,R31,R32,R33,R34,R35,R36,R37,R40,R44,R46,R52,R54,R59,R61,R65,R67 | 31 | 10k | Resistor_SMD:R_0603_1608Metric_Pad0.98x0.95mm_HandSolder
R7 | 1 | 4k7 | Resistor_SMD:R_0603_1608Metric_Pad0.98x0.95mm_HandSolder
R8,R9 | 2 | 5k1 | Resistor_SMD:R_0603_1608Metric_Pad0.98x0.95mm_HandSolder
R17,R18,R19,R20,R21,R22,R23 | 7 | 680/510 | Resistor_SMD:R_0603_1608Metric_Pad0.98x0.95mm_HandSolder
R38,R39 | 2 | 680 | Resistor_SMD:R_0603_1608Metric_Pad0.98x0.95mm_HandSolder
R41,R45,R49,R53,R57,R60,R63,R66 | 8 | 634 | Resistor_SMD:R_0603_1608Metric_Pad0.98x0.95mm_HandSolder
R42,R47,R50,R55,R58,R62,R64,R68 | 8 | 91 | Resistor_SMD:R_0603_1608Metric_Pad0.98x0.95mm_HandSolder
R43,R48,R51,R56 | 4 | 470 | Resistor_SMD:R_0603_1608Metric_Pad0.98x0.95mm_HandSolder
RV1,RV2,RV3 | 3 | CG0402MLU-12G | library:VARC1005X41N | ESD Suppressors / TVS Diodes CHIP GUARD 12VOLT
RV4 | 1 | R_Potentiometer | Potentiometer_THT:Potentiometer_Alpha_RD901F-40-00D_Single_Vertical_CircularHoles | Potentiometer
SW1 | 1 | RotaryEncoder_Switch | Rotary_Encoder:RotaryEncoder_Alps_EC11E-Switch_Vertical_H20mm_CircularMountingHoles | Rotary encoder, dual channel, incremental quadrate outputs, with switch
SW2,SW3,SW4,SW5,SW6,SW7,SW8,SW9,SW10,SW11 | 10 | SW_Push | Button_Switch_THT:SW_TH_Tactile_Omron_B3F-102x
U1,U2 | 2 | TLV76133DCY | Package_TO_SOT_SMD:SOT-223-3_TabPin2 | 3.3V, 1A, Low Noise, High-PSRR LDO Regulator, 2.5V...16V input, SOT-223
U3,U4 | 2 | MCP6004 | Package_SO:TSSOP-14_4.4x5mm_P0.65mm

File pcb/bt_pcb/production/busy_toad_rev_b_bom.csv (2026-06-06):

Designator | Footprint | Quantity | Value | LCSC Part #
C1, C10, C12, C15, C19, C22, C23, C24, C3, C33, C34, C36, C39, C41, C43, C44, C46, C47, C48, C49, C5, C50, C51, C52, C54, C55, C56, C57, C59, C60, C61, C62, C64, C66, C68, C7, C70, C80, C88 | 0603 | 39 | 100n
C11, C17, C2, C26, C27, C29, C30, C31, C4, C45, C6, C74, C77, C79, C81, C84, C86, C87, C92, C94, C98 | 0805 | 21 | 10u
C13, C25, C28, C32, C35, C37, C38, C40, C42, C63, C65, C8 | 0603 | 12 | 1u
C14, C53, C58, C67, C69, C71, C72, C9 | 0603 | 8 | 2.2u
C16, C18, C20, C21 | 0805 | 4 | 22u
C73, C76, C78, C83, C85, C90, C93, C96 | 0603 | 8 | 470p
C75, C82, C89, C95 | 0603 | 4 | 2.7n
C91, C97 | 0603 | 2 | 10n
D1, D2 | SOD3716X125N | 2 | B5819W
D10, D12, D14, D16, D4, D6, D8 | LED_D3.0mm | 7 | LED
D11, D13, D15, D17, D18, D3, D5, D7, D9 | 0603 | 9 | LED
IC1 | SOT95P280X145-6N | 1 | LV3842XDBVR
IC2 | QFN40P600X600X80-49N-D | 1 | CS4282P
IC3 | TAD5242IRGER | 1 | TAD5242IRGER
IC4 | QFP50P1600X1600X160-100N | 1 | STM32H750VBT6
IC5 | QFP50P900X900X160-48N | 1 | STM32H523CET6
J14 | microSD_HC_Molex_104031-0811 | 1 | Micro_SD_Card_Det2
J15, J16, J17, J18 | NYS-216G | 4 | ReanNYS216G
J2 | 694106301002_1 | 1 | Barrel_Jack_Switch
J7 | USB_C_Receptacle_GCT_USB4105-xx-A_16P_TopMnt_Horizontal | 1 | USB_C_Receptacle_USB2.0_16P
L1 | SRR6040A180M | 1 | 18uH 1.5A
R1 | 0603 | 1 | 100k
R10, R11, R12, R13, R14, R15, R16, R24, R25, R26, R27, R28, R29, R30, R31, R32, R33, R34, R35, R36, R37, R40, R44, R46, R52, R54, R59, R6, R61, R65, R67 | 0603 | 31 | 10k
R17, R18, R19, R20, R21, R22, R23 | 0603 | 7 | 680/510
R2, R3 | 0603 | 2 | 47k
R38, R39 | 0603 | 2 | 680
R4, R5 | 0603 | 2 | 22
R41, R45, R49, R53, R57, R60, R63, R66 | 0603 | 8 | 634
R42, R47, R50, R55, R58, R62, R64, R68 | 0603 | 8 | 91
R43, R48, R51, R56 | 0603 | 4 | 470
R7 | 0603 | 1 | 4k7
R8, R9 | 0603 | 2 | 5k1
RV1, RV2, RV3 | VARC1005X41N | 3 | CG0402MLU-12G
RV4 | Potentiometer_Alpha_RD901F-40-00D_Single_Vertical_CircularHoles | 1 | R_Potentiometer
SW1 | RotaryEncoder_Alps_EC11E-Switch_Vertical_H20mm_CircularMountingHoles | 1 | RotaryEncoder_Switch
SW10, SW11, SW2, SW3, SW4, SW5, SW6, SW7, SW8, SW9 | SW_TH_Tactile_Omron_B3F-102x | 10 | SW_Push
U1, U2 | SOT-223-3_TabPin2 | 2 | TLV76133DCY
U3, U4 | TSSOP-14_4.4x5mm_P0.65mm | 2 | MCP6004

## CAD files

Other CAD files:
cad/drafts/profile.FCStd

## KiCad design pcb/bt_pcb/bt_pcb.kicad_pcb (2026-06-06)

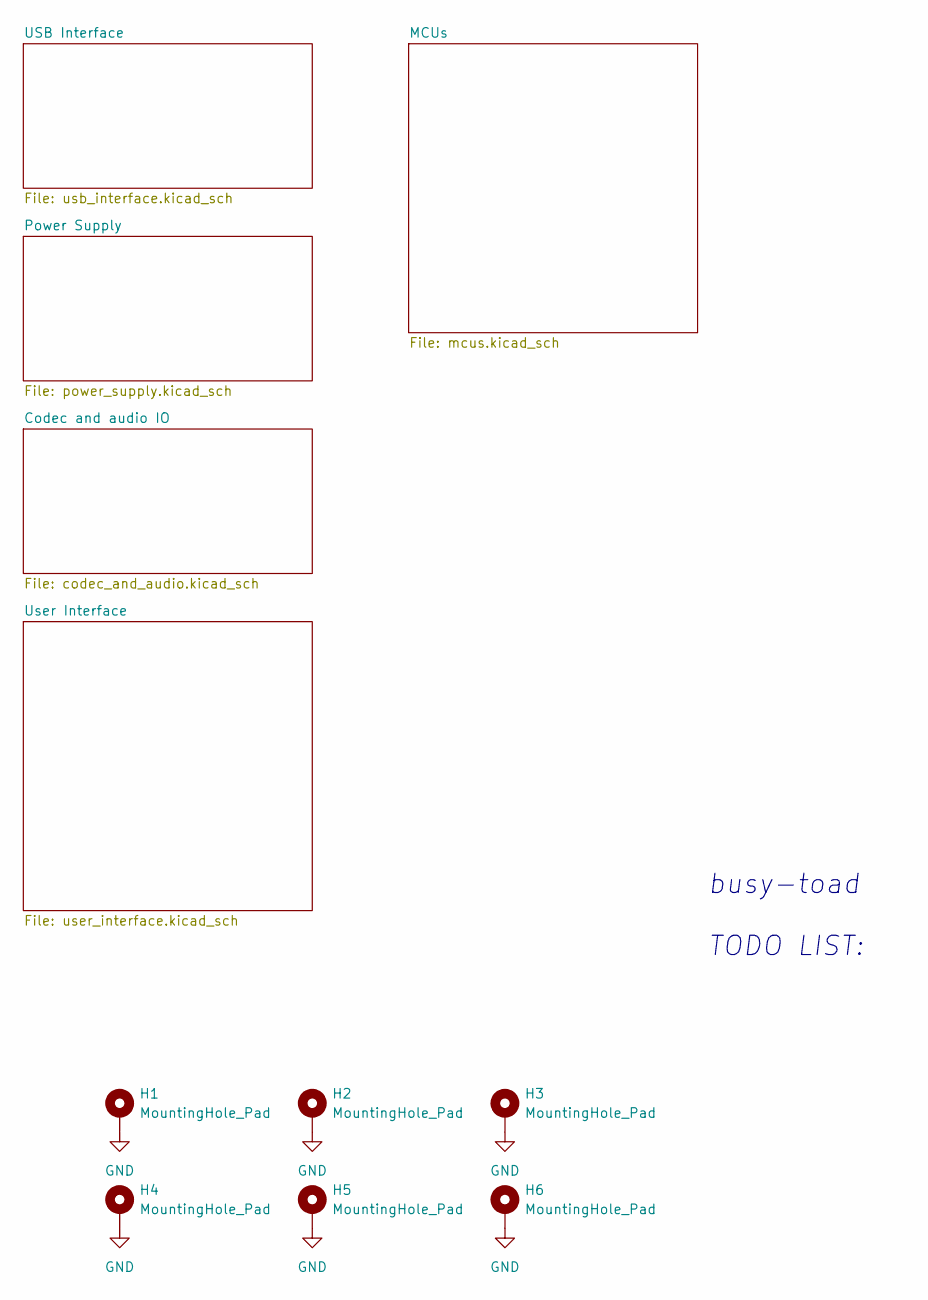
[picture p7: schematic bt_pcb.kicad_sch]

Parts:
H1, H2, H3, H4, H5, H6: MountingHole_Pad; MountingHole_3.2mm_M3_ISO14580_Pad

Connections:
GND: H1.1 (1_1), H2.1 (1_1), H3.1 (1_1), H4.1 (1_1), H5.1 (1_1), H6.1 (1_1); also elsewhere on the board

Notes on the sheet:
busy-toad TODO LIST:

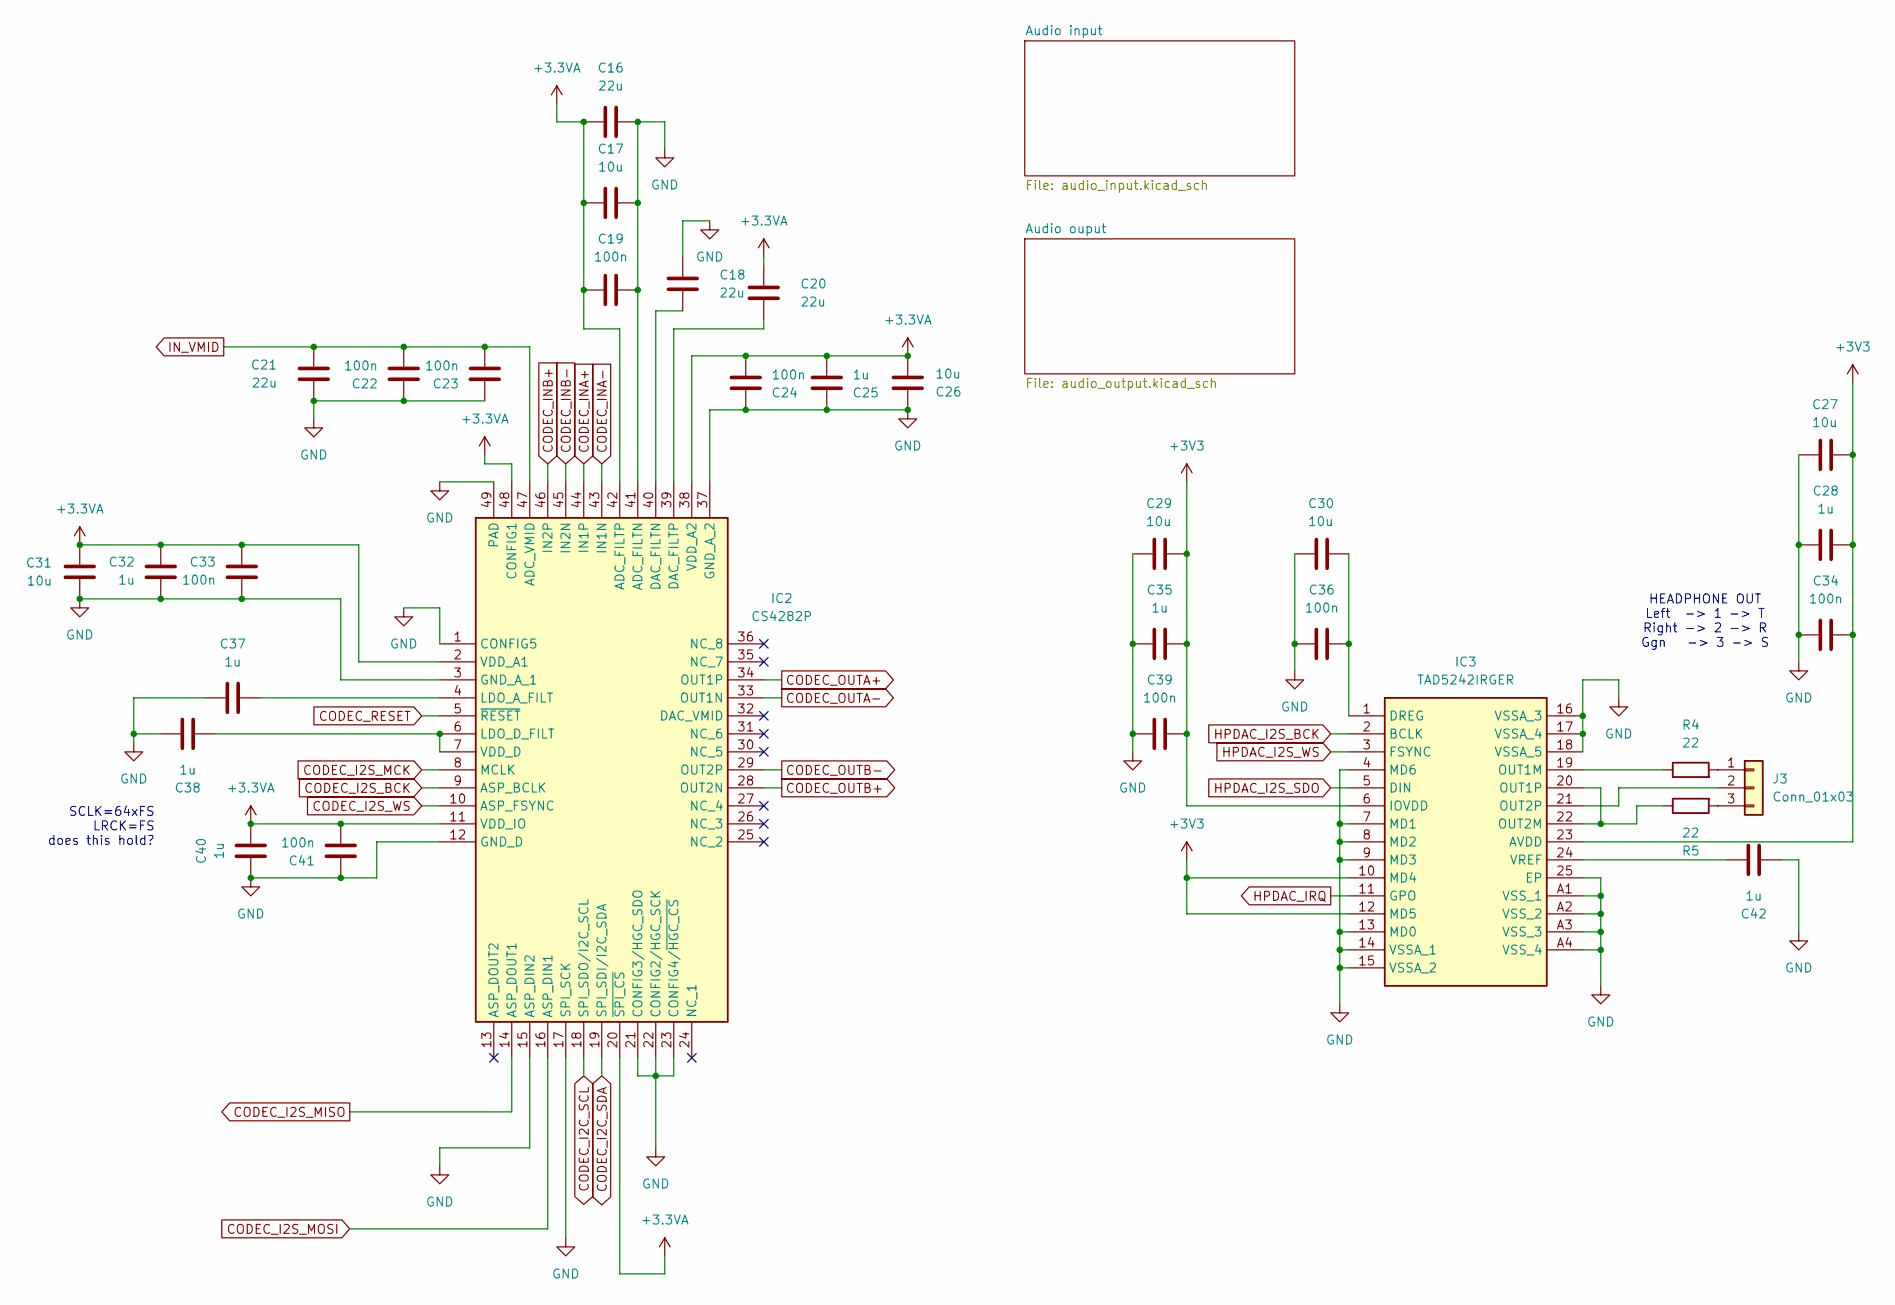
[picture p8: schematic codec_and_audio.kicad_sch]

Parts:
C16, C18, C20, C21: 22u; C_0805_2012Metric_Pad1.18x1.45mm_HandSolder
C17, C26, C27, C29, C30, C31: 10u; C_0805_2012Metric_Pad1.18x1.45mm_HandSolder
C19, C22, C23, C24, C33, C34, C36, C39, C41: 100n; C_0603_1608Metric_Pad1.08x0.95mm_HandSolder
C25, C28, C32, C35, C37, C38, C40, C42: 1u; C_0603_1608Metric_Pad1.08x0.95mm_HandSolder
IC2: CS4282P; QFN40P600X600X80-49N-D; Manufacturer_Part_Number CS4282P
IC3: TAD5242IRGER; Manufacturer_Part_Number TAD5242IRGER; Mouser Part Number 595-TAD5242IRGER
J3: Conn_01x03; JST_PH_B3B-PH-K_1x03_P2.00mm_Vertical
R4, R5: 22; R_0603_1608Metric_Pad0.98x0.95mm_HandSolder

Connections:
+3.3VA: C16.1, C17.2, C19.2, C20.1, C24.2, C25.2, C26.2, C31.1, C32.1, C33.1, C40.1, C41.2, IC2.2 (VDD_A1), IC2.11 (VDD_IO), IC2.20 (~SPI_CS), IC2.38 (VDD_A2), IC2.42 (ADC_FILTP), IC2.48 (CONFIG1); also elsewhere on the board
+3V3: C27.1, C28.1, C29.1, C34.2, C35.1, C39.2, IC3.6 (IOVDD), IC3.10 (MD4), IC3.12 (MD5), IC3.23 (AVDD); also elsewhere on the board
CODEC_I2C_SCL: IC2.18 (SPI_SDO/I2C_SCL); also elsewhere on the board
CODEC_I2C_SDA: IC2.19 (SPI_SDI/I2C_SDA); also elsewhere on the board
CODEC_I2S_BCK: IC2.9 (ASP_BCLK); also elsewhere on the board
CODEC_I2S_MCK: IC2.8 (MCLK); also elsewhere on the board
CODEC_I2S_MISO: IC2.14 (ASP_DOUT1); also elsewhere on the board
CODEC_I2S_MOSI: IC2.16 (ASP_DIN1); also elsewhere on the board
CODEC_I2S_WS: IC2.10 (ASP_FSYNC); also elsewhere on the board
CODEC_INA+: IC2.44 (IN1P); also elsewhere on the board
CODEC_INA-: IC2.43 (IN1N); also elsewhere on the board
CODEC_INB+: IC2.46 (IN2P); also elsewhere on the board
CODEC_INB-: IC2.45 (IN2N); also elsewhere on the board
CODEC_OUTA+: IC2.34 (OUT1P); also elsewhere on the board
CODEC_OUTA-: IC2.33 (OUT1N); also elsewhere on the board
CODEC_OUTB+: IC2.28 (OUT2N); also elsewhere on the board
CODEC_OUTB-: IC2.29 (OUT2P); also elsewhere on the board
CODEC_RESET: IC2.5 (~RESET); also elsewhere on the board
GND: C16.2, C17.1, C18.1, C19.1, C21.2, C22.1, C23.1, C24.1, C25.1, C26.1, C27.2, C28.2, C29.2, C30.2, C31.2, C32.2, C33.2, C34.1, C35.2, C36.1, C37.2, C38.2, C39.1, C40.2, C41.1, C42.2, IC2.1 (CONFIG5), IC2.3 (GND_A_1), IC2.12 (GND_D), IC2.15 (ASP_DIN2), IC2.17 (SPI_SCK), IC2.21 (CONFIG3/HGC_SDO), IC2.22 (CONFIG2/HGC_SCK), IC2.23 (CONFIG4/~HGC_CS), IC2.37 (GND_A_2), IC2.41 (ADC_FILTN), IC2.49 (PAD), IC3.4 (MD6), IC3.7 (MD1), IC3.8 (MD2), IC3.9 (MD3), IC3.13 (MD0), IC3.14 (VSSA_1), IC3.15 (VSSA_2), IC3.16 (VSSA_3), IC3.17 (VSSA_4), IC3.18 (VSSA_5), IC3.25 (EP), IC3.A1 (VSS_1), IC3.A2 (VSS_2), IC3.A3 (VSS_3), IC3.A4 (VSS_4); also elsewhere on the board
HPDAC_I2S_BCK: IC3.2 (BCLK); also elsewhere on the board
HPDAC_I2S_SDO: IC3.5 (DIN); also elsewhere on the board
HPDAC_I2S_WS: IC3.3 (FSYNC); also elsewhere on the board
HPDAC_IRQ: IC3.11 (GPO); also elsewhere on the board
IN_VMID: C21.1, C22.2, C23.2, IC2.47 (ADC_VMID); also elsewhere on the board
unnamed: C18.2, IC2.40 (DAC_FILTN)
unnamed: C20.2, IC2.39 (DAC_FILTP)
unnamed: C37.1, IC2.4 (LDO_A_FILT)
unnamed: C38.1, IC2.6 (LDO_D_FILT), IC2.7 (VDD_D)
unnamed: C30.1, C36.2, IC3.1 (DREG)
unnamed: IC3.19 (OUT1M), R4.1
unnamed: IC3.20 (OUT1P), IC3.22 (OUT2M), R5.1
unnamed: IC3.21 (OUT2P), J3.2
unnamed: C42.1, IC3.24 (VREF)
unnamed: J3.1, R4.2
unnamed: J3.3, R5.2

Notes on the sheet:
HEADPHONE OUT Left -> 1 -> T Right -> 2 -> R Ggn -> 3 -> S
SCLK=64xFS LRCK=FS does this hold?

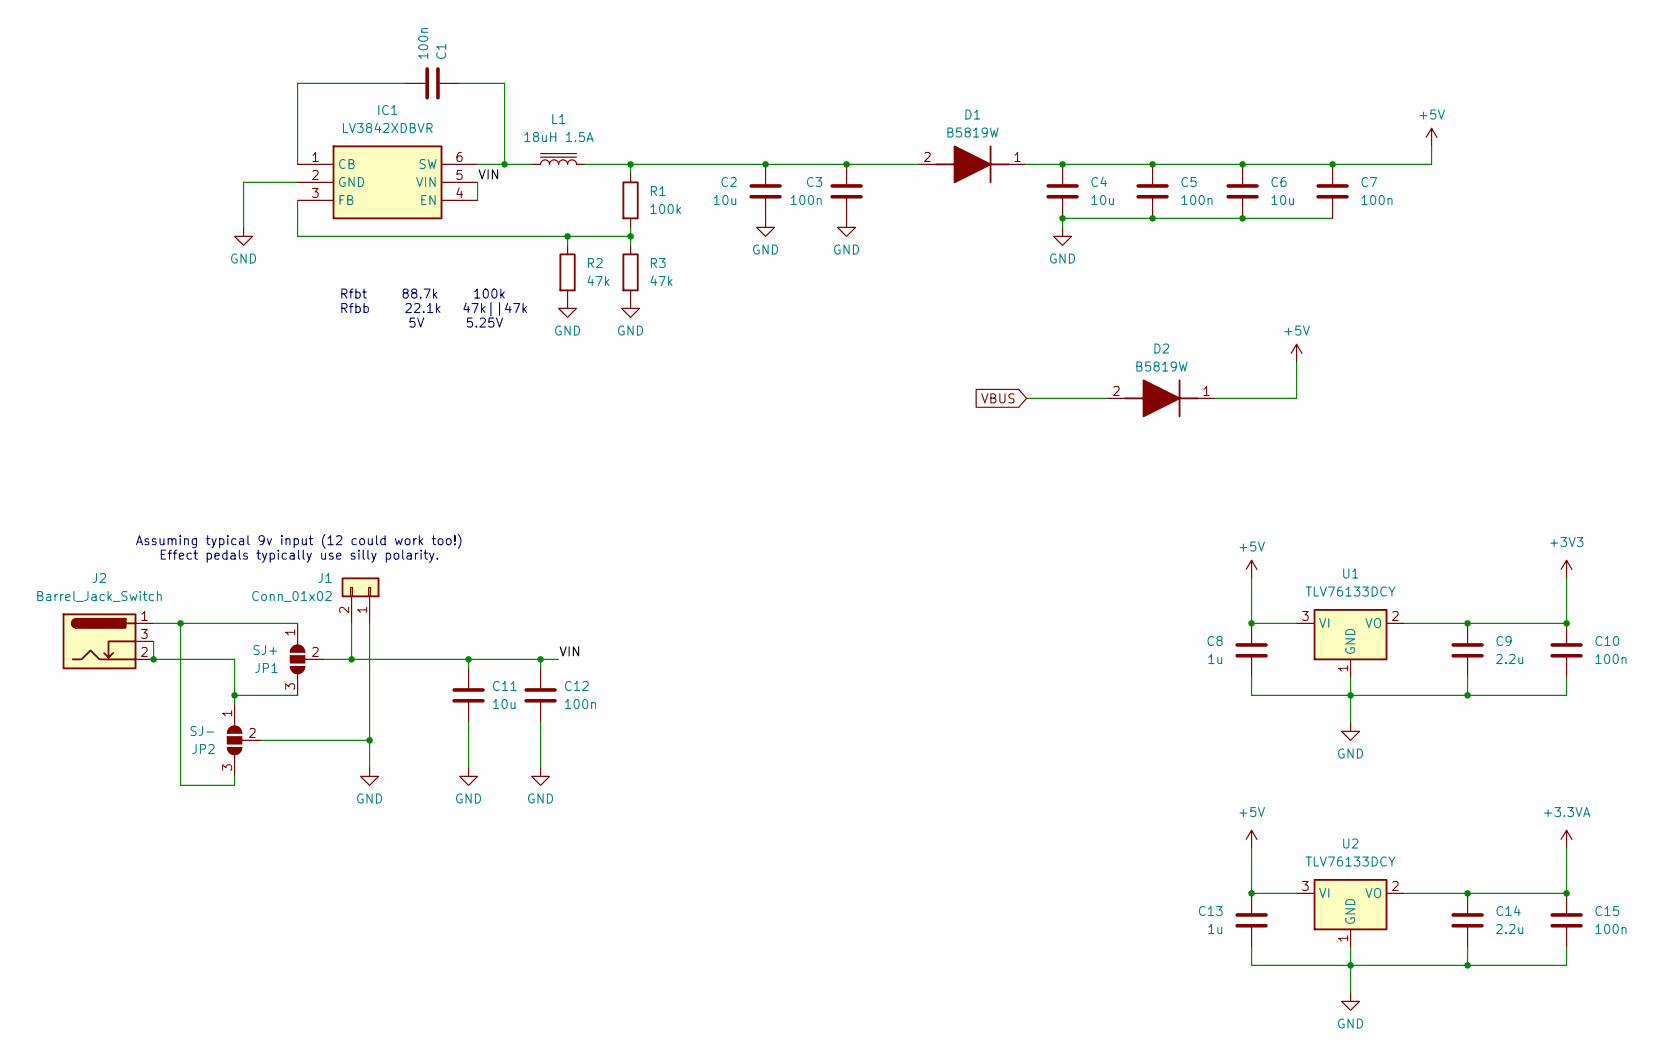
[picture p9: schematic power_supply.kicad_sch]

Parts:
C1, C3, C5, C7, C10, C12, C15: 100n; C_0603_1608Metric_Pad1.08x0.95mm_HandSolder
C2, C4, C6, C11: 10u; C_0805_2012Metric_Pad1.18x1.45mm_HandSolder
C8, C13: 1u; C_0603_1608Metric_Pad1.08x0.95mm_HandSolder
C9, C14: 2.2u; C_0603_1608Metric_Pad1.08x0.95mm_HandSolder
D1, D2: B5819W; SOD3716X125N; Manufacturer_Part_Number B5819W
IC1: LV3842XDBVR; SOT95P280X145-6N; Manufacturer_Part_Number LV3842XDBVR; Mouser Part Number 595-LV3842XDBVR
J1: Conn_01x02; PinHeader_1x02_P2.54mm_Vertical
J2: Barrel_Jack_Switch; 694106301002_1
JP1: SJ+; SolderJumper-3_P1.3mm_Open_Pad1.0x1.5mm
JP2: SJ-; SolderJumper-3_P1.3mm_Open_Pad1.0x1.5mm
L1: 18uH 1.5A; SRR6040A180M
R1: 100k; R_0603_1608Metric_Pad0.98x0.95mm_HandSolder
R2, R3: 47k; R_0603_1608Metric_Pad0.98x0.95mm_HandSolder
U1, U2: TLV76133DCY; SOT-223-3_TabPin2

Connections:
+3.3VA: C14.2, C15.1, U2.2 (VO); also elsewhere on the board
+3V3: C9.2, C10.1, U1.2 (VO); also elsewhere on the board
+5V: C4.1, C5.1, C6.1, C7.1, C8.2, C13.2, D1.1 (K), D2.1 (K), U1.3 (VI), U2.3 (VI)
/Power Supply/VIN: C11.1, C12.1, IC1.4 (EN), IC1.5 (VIN), J1.2, JP1.2 (C)
GND: C2.2, C3.2, C4.2, C5.2, C6.2, C7.2, C8.1, C9.1, C10.2, C11.2, C12.2, C13.1, C14.1, C15.2, IC1.2 (GND), J1.1, JP2.2 (C), R2.2, R3.2, U1.1 (GND), U2.1 (GND); also elsewhere on the board
unnamed: C2.1, C3.1, D1.2 (A), L1.2, R1.1
unnamed: C1.2, IC1.1 (CB)
unnamed: IC1.3 (FB), R1.2, R2.1, R3.1
unnamed: C1.1, IC1.6 (SW), L1.1
unnamed: J2.1, JP1.1 (A), JP2.3 (B)
unnamed: J2.2, J2.3, JP1.3 (B), JP2.1 (A)
VBUS: D2.2 (A); also elsewhere on the board

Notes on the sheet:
Assuming typical 9v input (12 could work too!) Effect pedals typically use silly polarity.
Rfbt 88.7k 100k Rfbb 22.1k 47k||47k 5V 5.25V

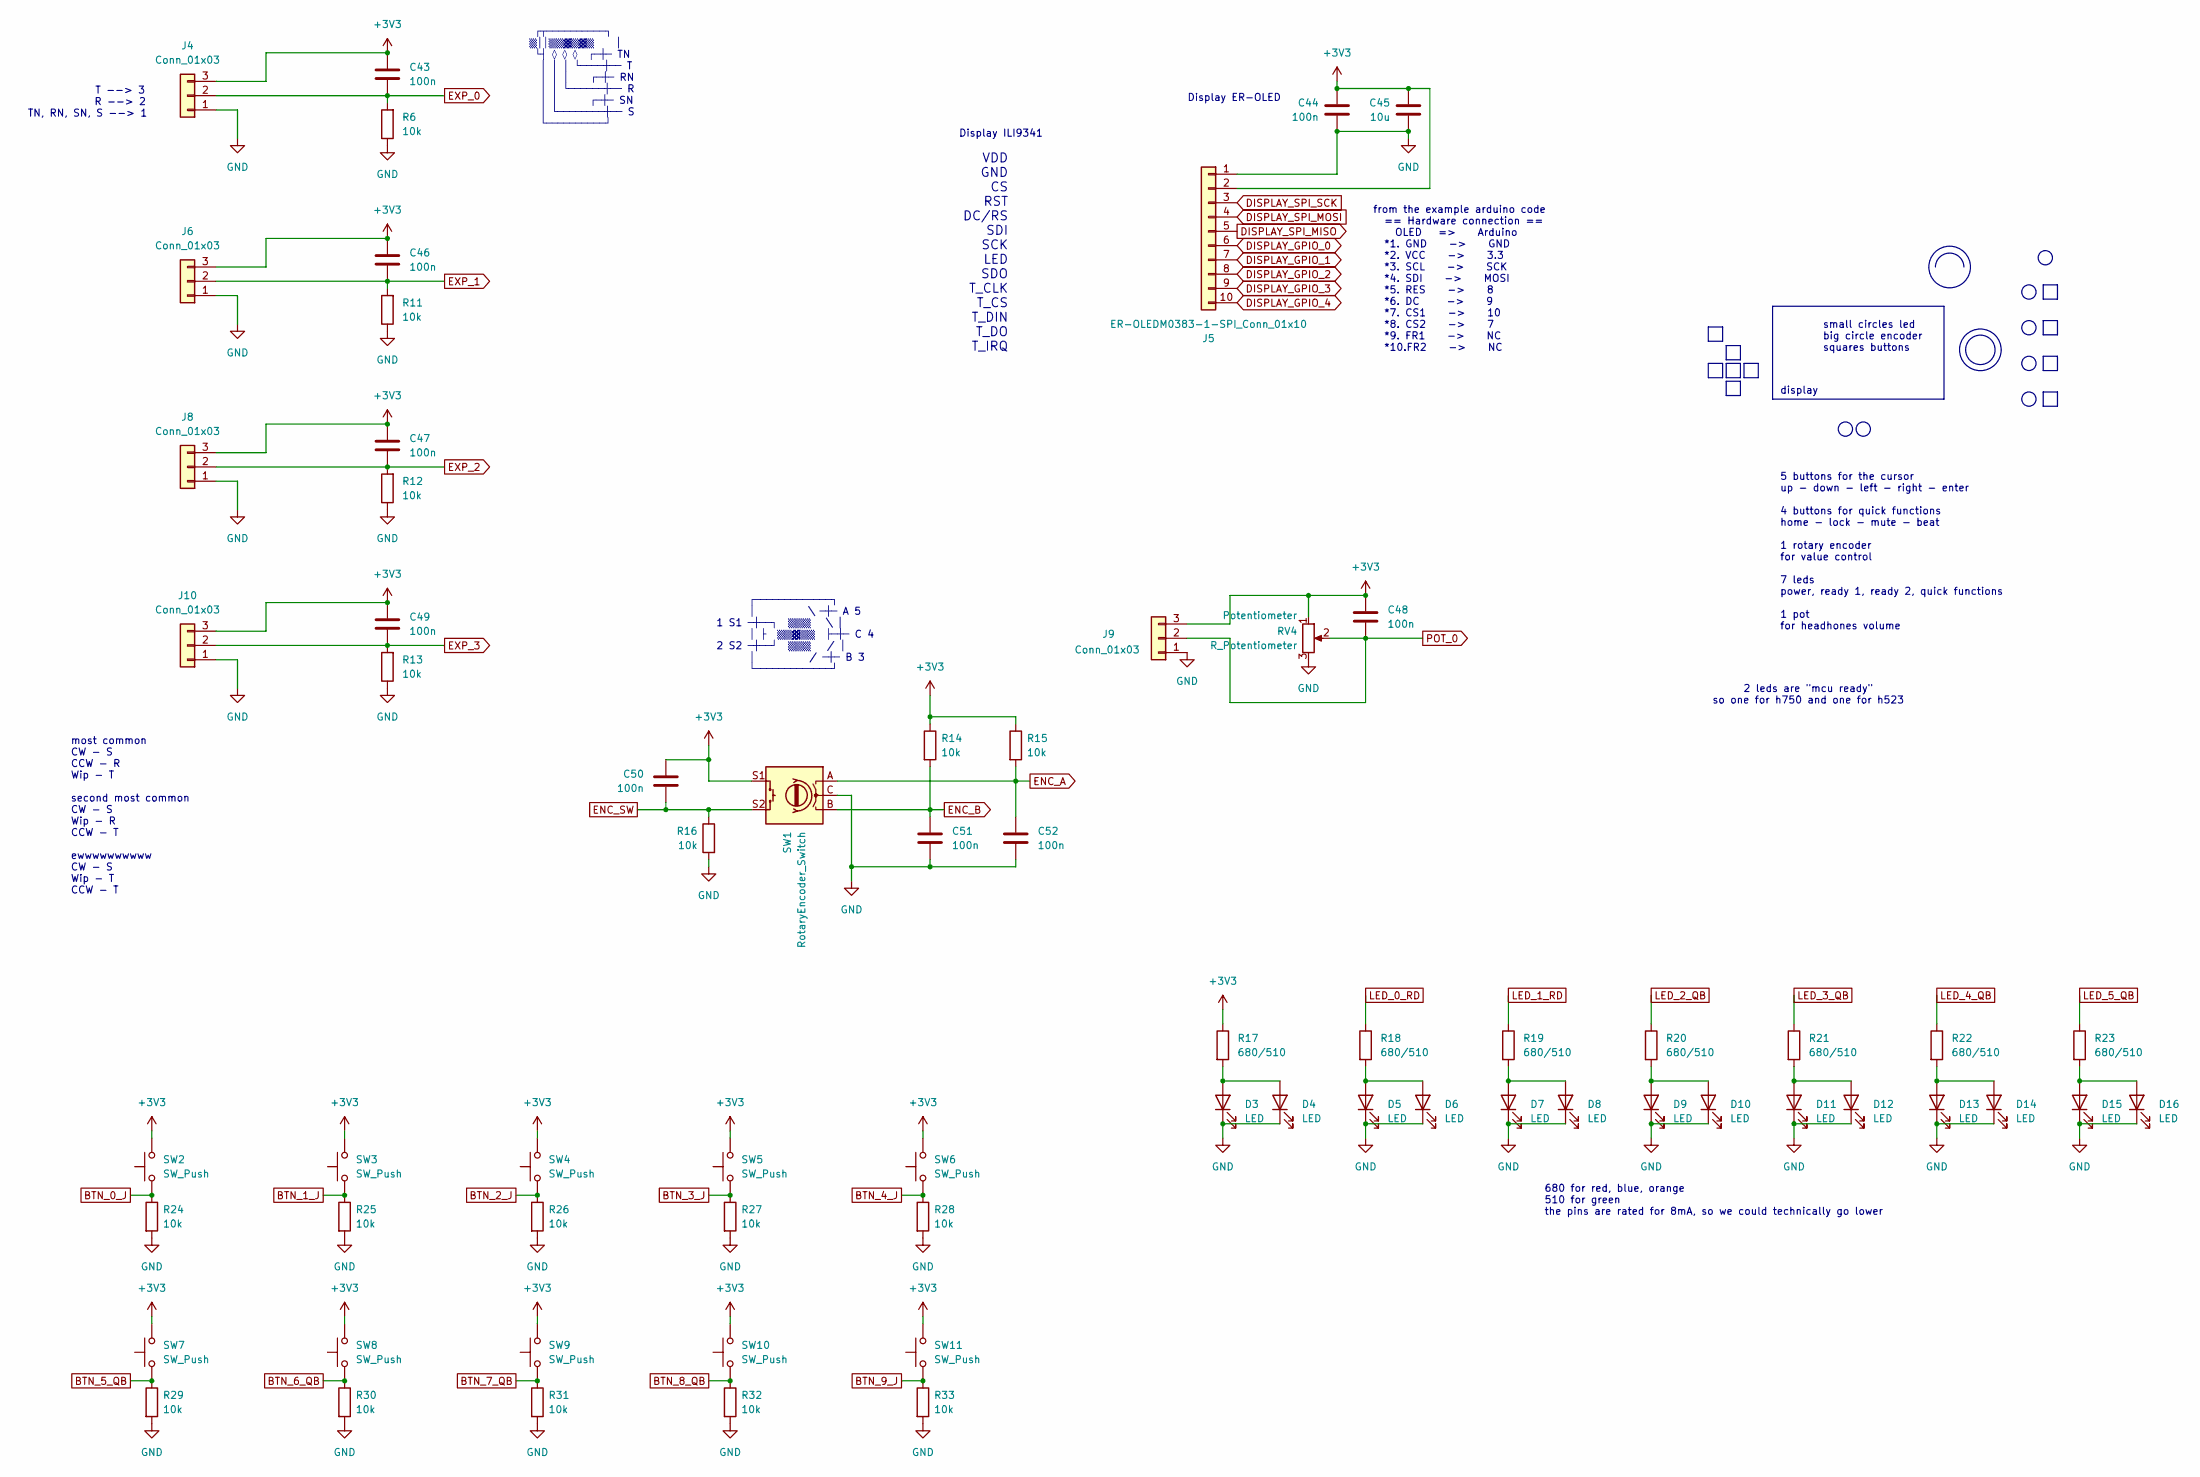
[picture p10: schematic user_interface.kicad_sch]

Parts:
C43, C44, C46, C47, C48, C49, C50, C51, C52: 100n; C_0603_1608Metric_Pad1.08x0.95mm_HandSolder
C45: 10u; C_0805_2012Metric_Pad1.18x1.45mm_HandSolder
D3, D5, D7, D9, D11, D13, D15: LED; LED_0603_1608Metric_Pad1.05x0.95mm_HandSolder
D4, D6, D8, D10, D12, D14, D16: LED; LED_D3.0mm
J4, J6, J8, J9, J10: Conn_01x03; JST_PH_B3B-PH-K_1x03_P2.00mm_Vertical
J5: ER-OLEDM0383-1-SPI_Conn_01x10; ER-OLEDM0383-1-SPI
R6, R11, R12, R13, R14, R15, R16, R24, R25, R26, R27, R28, R29, R30, R31, R32, R33: 10k; R_0603_1608Metric_Pad0.98x0.95mm_HandSolder
R17, R18, R19, R20, R21, R22, R23: 680/510; R_0603_1608Metric_Pad0.98x0.95mm_HandSolder
RV4: R_Potentiometer; Potentiometer_Alpha_RD901F-40-00D_Single_Vertical_CircularH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
SW1: RotaryEncoder_Switch; RotaryEncoder_Alps_EC11E-Switch_Vertical_H20mm_CircularMoun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
SW2, SW3, SW4, SW5, SW6, SW7, SW8, SW9, SW10, SW11: SW_Push; SW_TH_Tactile_Omron_B3F-102x

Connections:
+3V3: C43.1, C44.2, C45.2, C46.1, C47.1, C48.1, C49.1, C50.1, J4.3, J5.2, J6.3, J8.3, J9.3, J10.3, R14.1, R15.1, R17.1, RV4.1, SW1.S1, SW2.2, SW3.2, SW4.2, SW5.2, SW6.2, SW7.2, SW8.2, SW9.2, SW10.2, SW11.2; also elsewhere on the board
BTN_0_J: R24.1, SW2.1; also elsewhere on the board
BTN_1_J: R25.1, SW3.1; also elsewhere on the board
BTN_2_J: R26.1, SW4.1; also elsewhere on the board
BTN_3_J: R27.1, SW5.1; also elsewhere on the board
BTN_4_J: R28.1, SW6.1; also elsewhere on the board
BTN_5_QB: R29.1, SW7.1; also elsewhere on the board
BTN_6_QB: R30.1, SW8.1; also elsewhere on the board
BTN_7_QB: R31.1, SW9.1; also elsewhere on the board
BTN_8_QB: R32.1, SW10.1; also elsewhere on the board
BTN_9_J: R33.1, SW11.1; also elsewhere on the board
DISPLAY_GPIO_0: J5.6; also elsewhere on the board
DISPLAY_GPIO_1: J5.7; also elsewhere on the board
DISPLAY_GPIO_2: J5.8; also elsewhere on the board
DISPLAY_GPIO_3: J5.9; also elsewhere on the board
DISPLAY_GPIO_4: J5.10; also elsewhere on the board
DISPLAY_SPI_MISO: J5.5; also elsewhere on the board
DISPLAY_SPI_MOSI: J5.4; also elsewhere on the board
DISPLAY_SPI_SCK: J5.3; also elsewhere on the board
ENC_A: C52.1, R15.2, SW1.A; also elsewhere on the board
ENC_B: C51.1, R14.2, SW1.B; also elsewhere on the board
ENC_SW: C50.2, R16.1, SW1.S2; also elsewhere on the board
EXP_0: C43.2, J4.2, R6.2; also elsewhere on the board
EXP_1: C46.2, J6.2, R11.2; also elsewhere on the board
EXP_2: C47.2, J8.2, R12.2; also elsewhere on the board
EXP_3: C49.2, J10.2, R13.2; also elsewhere on the board
GND: C44.1, C45.1, C51.2, C52.2, D3.1 (K), D4.1 (K), D5.1 (K), D6.1 (K), D7.1 (K), D8.1 (K), D9.1 (K), D10.1 (K), D11.1 (K), D12.1 (K), D13.1 (K), D14.1 (K), D15.1 (K), D16.1 (K), J4.1, J5.1, J6.1, J8.1, J9.1, J10.1, R6.1, R11.1, R12.1, R13.1, R16.2, R24.2, R25.2, R26.2, R27.2, R28.2, R29.2, R30.2, R31.2, R32.2, R33.2, RV4.3, SW1.C; also elsewhere on the board
LED_0_RD: R18.1; also elsewhere on the board
LED_1_RD: R19.1; also elsewhere on the board
LED_2_QB: R20.1; also elsewhere on the board
LED_3_QB: R21.1; also elsewhere on the board
LED_4_QB: R22.1; also elsewhere on the board
LED_5_QB: R23.1; also elsewhere on the board
unnamed: D3.2 (A), D4.2 (A), R17.2
unnamed: D5.2 (A), D6.2 (A), R18.2
unnamed: D7.2 (A), D8.2 (A), R19.2
unnamed: D9.2 (A), D10.2 (A), R20.2
unnamed: D11.2 (A), D12.2 (A), R21.2
unnamed: D13.2 (A), D14.2 (A), R22.2
unnamed: D15.2 (A), D16.2 (A), R23.2
POT_0: C48.2, J9.2, RV4.2; also elsewhere on the board

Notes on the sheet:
680 for red, blue, orange 510 for green the pins are rated for 8mA, so we could technically go lower
small circles led big circle encoder squares buttons
Display ER-OLED
Display ILI9341
from the example arduino code == Hardware connection == OLED => Arduino *1. GND -> GND *2. VCC -> 3.3 *3. SCL -> SCK *4. SDI -> MOSI *5. RES -> 8 *6. DC -> 9 *7. CS1 -> 10 *8. CS2 -> 7 *9. FR1 -> NC *10.FR2 -> NC
VDD GND CS RST DC/RS SDI SCK LED SDO T_CLK T_CS T_DIN T_DO T_IRQ
5 buttons for the cursor up - down - left - right - enter 4 buttons for quick functions home - lock - mute - beat 1 rotary encoder for value control 7 leds power, ready 1, ready 2, quick functions 1 pot for headhones volume
most common CW - S CCW - R Wip - T second most common CW - S Wip - R CCW - T ewwwwwwwwww CW - S Wip - T CCW - T
T --> 3 R --> 2 TN, RN, SN, S --> 1
display
┌─────────────┐ │ \ ─┼─ A 5 1 S1 ─┼──┐ ▒▒▒ \ │ │ ├ ▒▒▓▒▒ ├─┼─ C 4 2 S2 ─┼──┘ ▒▒▒ / │ │ / ─┼─ B 3 └─────────────┘
┌┬──────────┐ ▒││▒▒▓▒▓▒ │ └┤ ◊ ◊ ◊ ┌─┼─ TN │ │ │ └────┼── T │ │ │ ┌─┼─ RN │ │ └──────┼── R │ │ ┌─┼─ SN │ └────────┼── S └──────────┘
2 leds are "mcu ready" so one for h750 and one for h523

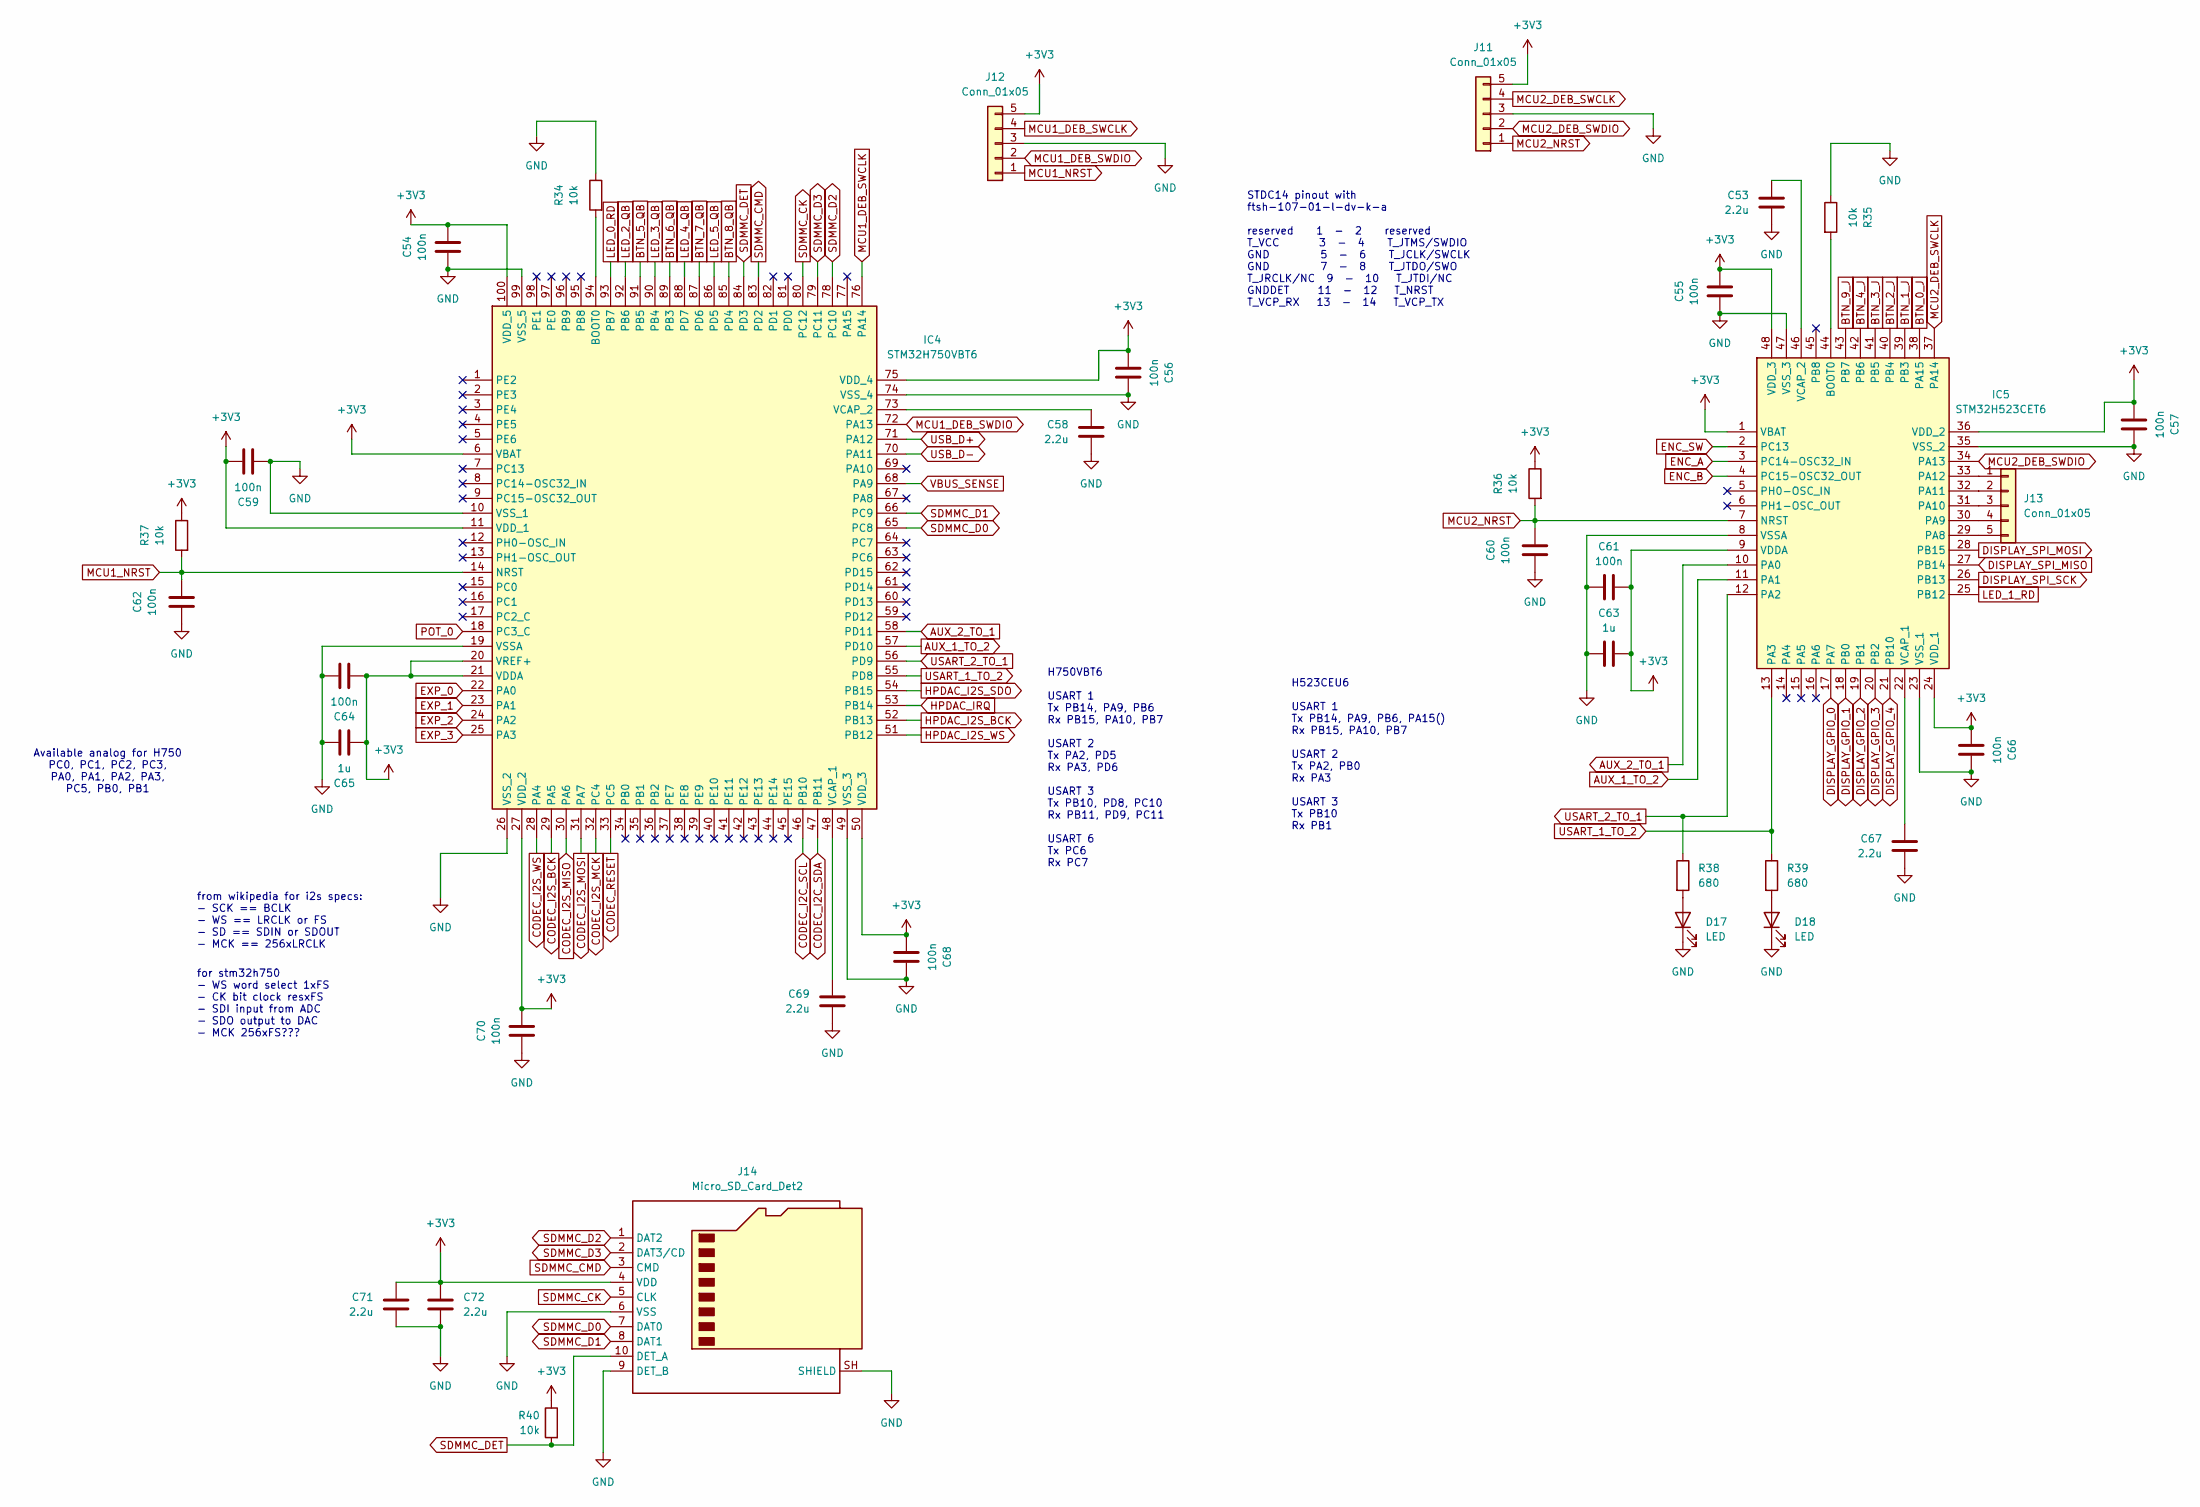
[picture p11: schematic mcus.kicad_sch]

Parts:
C53, C58, C67, C69, C71, C72: 2.2u; C_0603_1608Metric_Pad1.08x0.95mm_HandSolder
C54, C55, C56, C57, C59, C60, C61, C62, C64, C66, C68, C70: 100n; C_0603_1608Metric_Pad1.08x0.95mm_HandSolder
C63, C65: 1u; C_0603_1608Metric_Pad1.08x0.95mm_HandSolder
D17, D18: LED; LED_0603_1608Metric_Pad1.05x0.95mm_HandSolder
IC4: STM32H750VBT6; QFP50P1600X1600X160-100N; Manufacturer_Part_Number STM32H750VBT6; Mouser Part Number 511-STM32H750VBT6
IC5: STM32H523CET6; QFP50P900X900X160-48N; Manufacturer_Part_Number STM32H523CET6; Mouser Part Number 511-STM32H523CET6
J11, J12, J13: Conn_01x05; JST_PH_B5B-PH-K_1x05_P2.00mm_Vertical
J14: Micro_SD_Card_Det2; microSD_HC_Molex_104031-0811
R34, R35, R36, R37, R40: 10k; R_0603_1608Metric_Pad0.98x0.95mm_HandSolder
R38, R39: 680; R_0603_1608Metric_Pad0.98x0.95mm_HandSolder

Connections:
+3V3: C54.1, C55.1, C56.1, C57.1, C59.1, C61.1, C63.1, C64.1, C65.1, C66.1, C68.1, C70.2, C71.1, C72.1, IC4.6 (VBAT), IC4.11 (VDD_1), IC4.20 (VREF+), IC4.21 (VDDA), IC4.27 (VDD_2), IC4.50 (VDD_3), IC4.75 (VDD_4), IC4.100 (VDD_5), IC5.1 (VBAT), IC5.9 (VDDA), IC5.24 (VDD_1), IC5.36 (VDD_2), IC5.48 (VDD_3), J11.5, J12.5, J14.4 (VDD), R36.1, R37.1, R40.1; also elsewhere on the board
AUX_1_TO_2: IC4.57 (PD10), IC5.11 (PA1)
AUX_2_TO_1: IC4.58 (PD11), IC5.10 (PA0)
BTN_0_J: IC5.38 (PA15); also elsewhere on the board
BTN_1_J: IC5.39 (PB3); also elsewhere on the board
BTN_2_J: IC5.40 (PB4); also elsewhere on the board
BTN_3_J: IC5.41 (PB5); also elsewhere on the board
BTN_4_J: IC5.42 (PB6); also elsewhere on the board
BTN_5_QB: IC4.91 (PB5); also elsewhere on the board
BTN_6_QB: IC4.89 (PB3); also elsewhere on the board
BTN_7_QB: IC4.87 (PD6); also elsewhere on the board
BTN_8_QB: IC4.85 (PD4); also elsewhere on the board
BTN_9_J: IC5.43 (PB7); also elsewhere on the board
CODEC_I2C_SCL: IC4.46 (PB10); also elsewhere on the board
CODEC_I2C_SDA: IC4.47 (PB11); also elsewhere on the board
CODEC_I2S_BCK: IC4.29 (PA5); also elsewhere on the board
CODEC_I2S_MCK: IC4.32 (PC4); also elsewhere on the board
CODEC_I2S_MISO: IC4.30 (PA6); also elsewhere on the board
CODEC_I2S_MOSI: IC4.31 (PA7); also elsewhere on the board
CODEC_I2S_WS: IC4.28 (PA4); also elsewhere on the board
CODEC_RESET: IC4.33 (PC5); also elsewhere on the board
DISPLAY_GPIO_0: IC5.17 (PA7); also elsewhere on the board
DISPLAY_GPIO_1: IC5.18 (PB0); also elsewhere on the board
DISPLAY_GPIO_2: IC5.19 (PB1); also elsewhere on the board
DISPLAY_GPIO_3: IC5.20 (PB2); also elsewhere on the board
DISPLAY_GPIO_4: IC5.21 (PB10); also elsewhere on the board
DISPLAY_SPI_MISO: IC5.27 (PB14); also elsewhere on the board
DISPLAY_SPI_MOSI: IC5.28 (PB15); also elsewhere on the board
DISPLAY_SPI_SCK: IC5.26 (PB13); also elsewhere on the board
ENC_A: IC5.3 (PC14-OSC32_IN); also elsewhere on the board
ENC_B: IC5.4 (PC15-OSC32_OUT); also elsewhere on the board
ENC_SW: IC5.2 (PC13); also elsewhere on the board
EXP_0: IC4.22 (PA0); also elsewhere on the board
EXP_1: IC4.23 (PA1); also elsewhere on the board
EXP_2: IC4.24 (PA2); also elsewhere on the board
EXP_3: IC4.25 (PA3); also elsewhere on the board
GND: C53.2, C54.2, C55.2, C56.2, C57.2, C58.2, C59.2, C60.1, C61.2, C62.1, C63.2, C64.2, C65.2, C66.2, C67.2, C68.2, C69.2, C70.1, C71.2, C72.2, D17.1 (K), D18.1 (K), IC4.10 (VSS_1), IC4.19 (VSSA), IC4.26 (VSS_2), IC4.49 (VSS_3), IC4.74 (VSS_4), IC4.99 (VSS_5), IC5.8 (VSSA), IC5.23 (VSS_1), IC5.35 (VSS_2), IC5.47 (VSS_3), J11.3, J12.3, J14.6 (VSS), J14.9 (DET_B), J14.SH (SHIELD), R34.1, R35.1; also elsewhere on the board
HPDAC_I2S_BCK: IC4.52 (PB13); also elsewhere on the board
HPDAC_I2S_SDO: IC4.54 (PB15); also elsewhere on the board
HPDAC_I2S_WS: IC4.51 (PB12); also elsewhere on the board
HPDAC_IRQ: IC4.53 (PB14); also elsewhere on the board
LED_0_RD: IC4.93 (PB7); also elsewhere on the board
LED_1_RD: IC5.25 (PB12); also elsewhere on the board
LED_2_QB: IC4.92 (PB6); also elsewhere on the board
LED_3_QB: IC4.90 (PB4); also elsewhere on the board
LED_4_QB: IC4.88 (PD7); also elsewhere on the board
LED_5_QB: IC4.86 (PD5); also elsewhere on the board
MCU1_DEB_SWCLK: IC4.76 (PA14), J12.4
MCU1_DEB_SWDIO: IC4.72 (PA13), J12.2
MCU1_NRST: C62.2, IC4.14 (NRST), J12.1, R37.2
MCU2_DEB_SWCLK: IC5.37 (PA14), J11.4
MCU2_DEB_SWDIO: IC5.34 (PA13), J11.2
MCU2_NRST: C60.2, IC5.7 (NRST), J11.1, R36.2
unnamed: D17.2 (A), R38.2
unnamed: D18.2 (A), R39.2
unnamed: IC4.94 (BOOT0), R34.2
unnamed: C69.1, IC4.48 (VCAP_1)
unnamed: C58.1, IC4.73 (VCAP_2)
unnamed: IC5.44 (BOOT0), R35.2
unnamed: IC5.29 (PA8), J13.5
unnamed: IC5.30 (PA9), J13.4
unnamed: IC5.31 (PA10), J13.3
unnamed: IC5.32 (PA11), J13.2
unnamed: IC5.33 (PA12), J13.1
unnamed: C67.1, IC5.22 (VCAP_1)
unnamed: C53.1, IC5.46 (VCAP_2)
POT_0: IC4.18 (PC3_C); also elsewhere on the board
SDMMC_CK: IC4.80 (PC12), J14.5 (CLK)
SDMMC_CMD: IC4.83 (PD2), J14.3 (CMD)
SDMMC_D0: IC4.65 (PC8), J14.7 (DAT0)
SDMMC_D1: IC4.66 (PC9), J14.8 (DAT1)
SDMMC_D2: IC4.78 (PC10), J14.1 (DAT2)
SDMMC_D3: IC4.79 (PC11), J14.2 (DAT3/CD)
SDMMC_DET: IC4.84 (PD3), J14.10 (DET_A), R40.2
USART_1_TO_2: IC4.55 (PD8), IC5.13 (PA3), R39.1
USART_2_TO_1: IC4.56 (PD9), IC5.12 (PA2), R38.1
USB_D+: IC4.71 (PA12); also elsewhere on the board
USB_D-: IC4.70 (PA11); also elsewhere on the board
VBUS_SENSE: IC4.68 (PA9); also elsewhere on the board

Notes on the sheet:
H523CEU6 USART 1 Tx PB14, PA9, PB6, PA15() Rx PB15, PA10, PB7 USART 2 Tx PA2, PB0 Rx PA3 USART 3 Tx PB10 Rx PB1
for stm32h750 - WS word select 1xFS - CK bit clock resxFS - SDI input from ADC - SDO output to DAC - MCK 256xFS???
H750VBT6 USART 1 Tx PB14, PA9, PB6 Rx PB15, PA10, PB7 USART 2 Tx PA2, PD5 Rx PA3, PD6 USART 3 Tx PB10, PD8, PC10 Rx PB11, PD9, PC11 USART 6 Tx PC6 Rx PC7
STDC14 pinout with ftsh-107-01-l-dv-k-a reserved 1 - 2 reserved T_VCC 3 - 4 T_JTMS/SWDIO GND 5 - 6 T_JCLK/SWCLK GND 7 - 8 T_JTDO/SWO T_JRCLK/NC 9 - 10 T_JTDI/NC GNDDET 11 - 12 T_NRST T_VCP_RX 13 - 14 T_VCP_TX
from wikipedia for i2s specs: - SCK == BCLK - WS == LRCLK or FS - SD == SDIN or SDOUT - MCK == 256xLRCLK
Available analog for H750 PC0, PC1, PC2, PC3, PA0, PA1, PA2, PA3, PC5, PB0, PB1

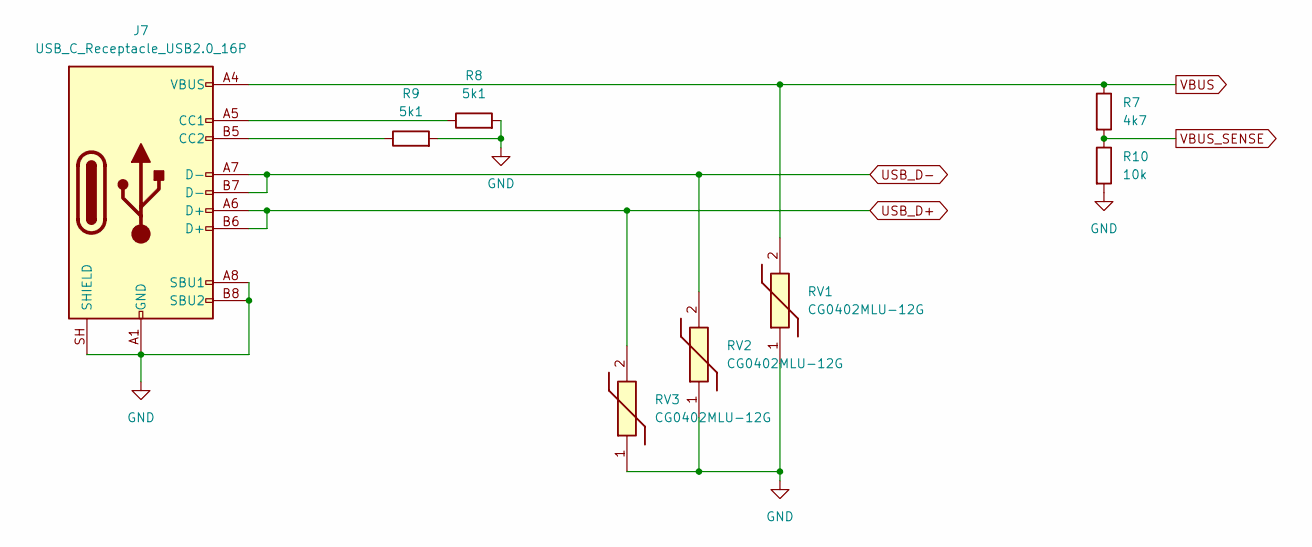
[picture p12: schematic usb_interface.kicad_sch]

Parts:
J7: USB_C_Receptacle_USB2.0_16P; USB_C_Receptacle_GCT_USB4105-xx-A_16P_TopMnt_Horizontal
R7: 4k7; R_0603_1608Metric_Pad0.98x0.95mm_HandSolder
R8, R9: 5k1; R_0603_1608Metric_Pad0.98x0.95mm_HandSolder
R10: 10k; R_0603_1608Metric_Pad0.98x0.95mm_HandSolder
RV1, RV2, RV3: CG0402MLU-12G; VARC1005X41N; Manufacturer_Part_Number CG0402MLU-12G; Mouser Part Number 652-CG0402MLU-12G

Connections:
GND: J7.A1 (GND), J7.A8 (SBU1), J7.A12 (GND), J7.B1 (GND), J7.B8 (SBU2), J7.B12 (GND), J7.SH (SHIELD), R8.2, R9.2, R10.2, RV1.1, RV2.1, RV3.1; also elsewhere on the board
unnamed: J7.A5 (CC1), R8.1
unnamed: J7.B5 (CC2), R9.1
USB_D+: J7.A6 (D+), J7.B6 (D+), RV3.2; also elsewhere on the board
USB_D-: J7.A7 (D-), J7.B7 (D-), RV2.2; also elsewhere on the board
VBUS: J7.A4 (VBUS), J7.A9 (VBUS), J7.B4 (VBUS), J7.B9 (VBUS), R7.1, RV1.2; also elsewhere on the board
VBUS_SENSE: R7.2, R10.1; also elsewhere on the board

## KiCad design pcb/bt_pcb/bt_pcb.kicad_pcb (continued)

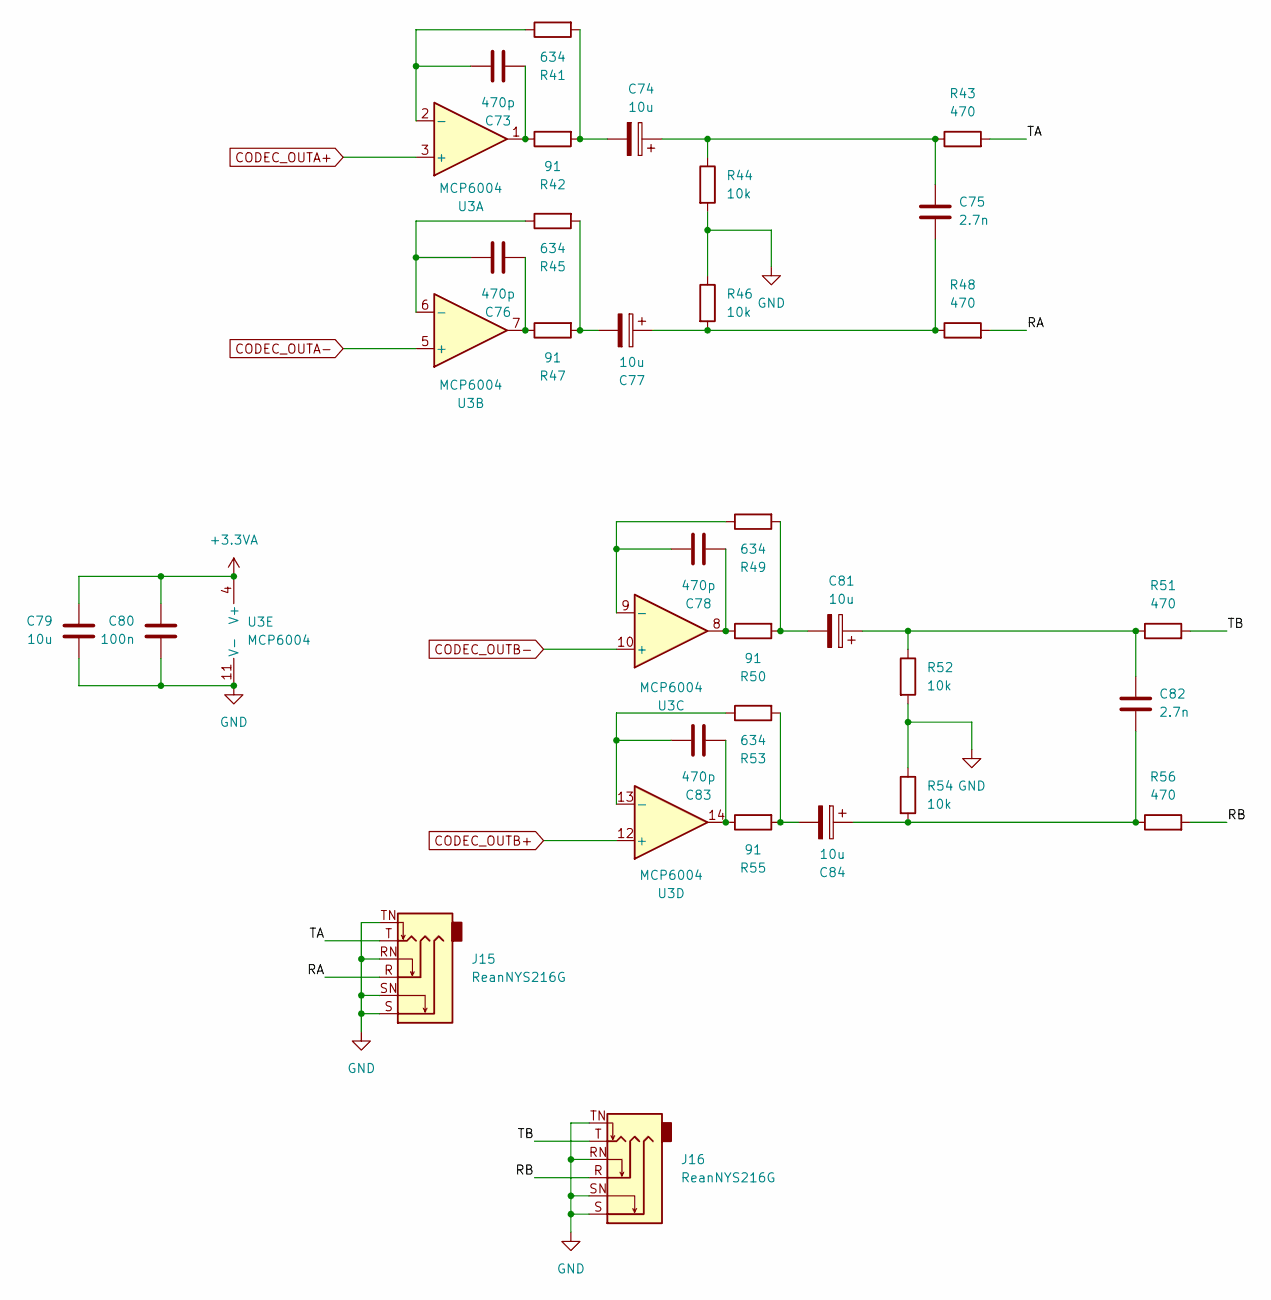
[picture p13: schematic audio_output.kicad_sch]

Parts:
C73, C76, C78, C83: 470p; C_0603_1608Metric_Pad1.08x0.95mm_HandSolder
C74, C77, C79, C81, C84: 10u; C_0805_2012Metric_Pad1.18x1.45mm_HandSolder
C75, C82: 2.7n; C_0603_1608Metric_Pad1.08x0.95mm_HandSolder
C80: 100n; C_0603_1608Metric_Pad1.08x0.95mm_HandSolder
J15, J16: ReanNYS216G; NYS-216G
R41, R45, R49, R53: 634; R_0603_1608Metric_Pad0.98x0.95mm_HandSolder
R42, R47, R50, R55: 91; R_0603_1608Metric_Pad0.98x0.95mm_HandSolder
R43, R48, R51, R56: 470; R_0603_1608Metric_Pad0.98x0.95mm_HandSolder
R44, R46, R52, R54: 10k; R_0603_1608Metric_Pad0.98x0.95mm_HandSolder
U3: MCP6004; TSSOP-14_4.4x5mm_P0.65mm

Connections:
+3.3VA: C79.1, C80.1, U3.4 (V+); also elsewhere on the board
/Codec and audio IO/Audio ouput/RA: J15.R, R48.2
/Codec and audio IO/Audio ouput/RB: J16.R, R56.2
/Codec and audio IO/Audio ouput/TA: J15.T, R43.2
/Codec and audio IO/Audio ouput/TB: J16.T, R51.2
CODEC_OUTA+: U3.3 (+); also elsewhere on the board
CODEC_OUTA-: U3.5 (+); also elsewhere on the board
CODEC_OUTB+: U3.12 (+); also elsewhere on the board
CODEC_OUTB-: U3.10 (+); also elsewhere on the board
GND: C79.2, C80.2, J15.RN, J15.S, J15.SN, J15.TN, J16.RN, J16.S, J16.SN, J16.TN, R44.2, R46.1, R52.2, R54.1, U3.11 (V-); also elsewhere on the board
unnamed: C73.1, R42.1, U3.1
unnamed: C74.1, C75.1, R43.1, R44.1
unnamed: C74.2, R41.2, R42.2
unnamed: C75.2, C77.1, R46.2, R48.1
unnamed: C76.1, R47.1, U3.7
unnamed: C77.2, R45.2, R47.2
unnamed: C78.1, R50.1, U3.8
unnamed: C81.1, C82.1, R51.1, R52.1
unnamed: C81.2, R49.2, R50.2
unnamed: C82.2, C84.1, R54.2, R56.1
unnamed: C83.1, R55.1, U3.14
unnamed: C84.2, R53.2, R55.2
unnamed: C73.2, R41.1, U3.2 (-)
unnamed: C76.2, R45.1, U3.6 (-)
unnamed: C78.2, R49.1, U3.9 (-)
unnamed: C83.2, R53.1, U3.13 (-)

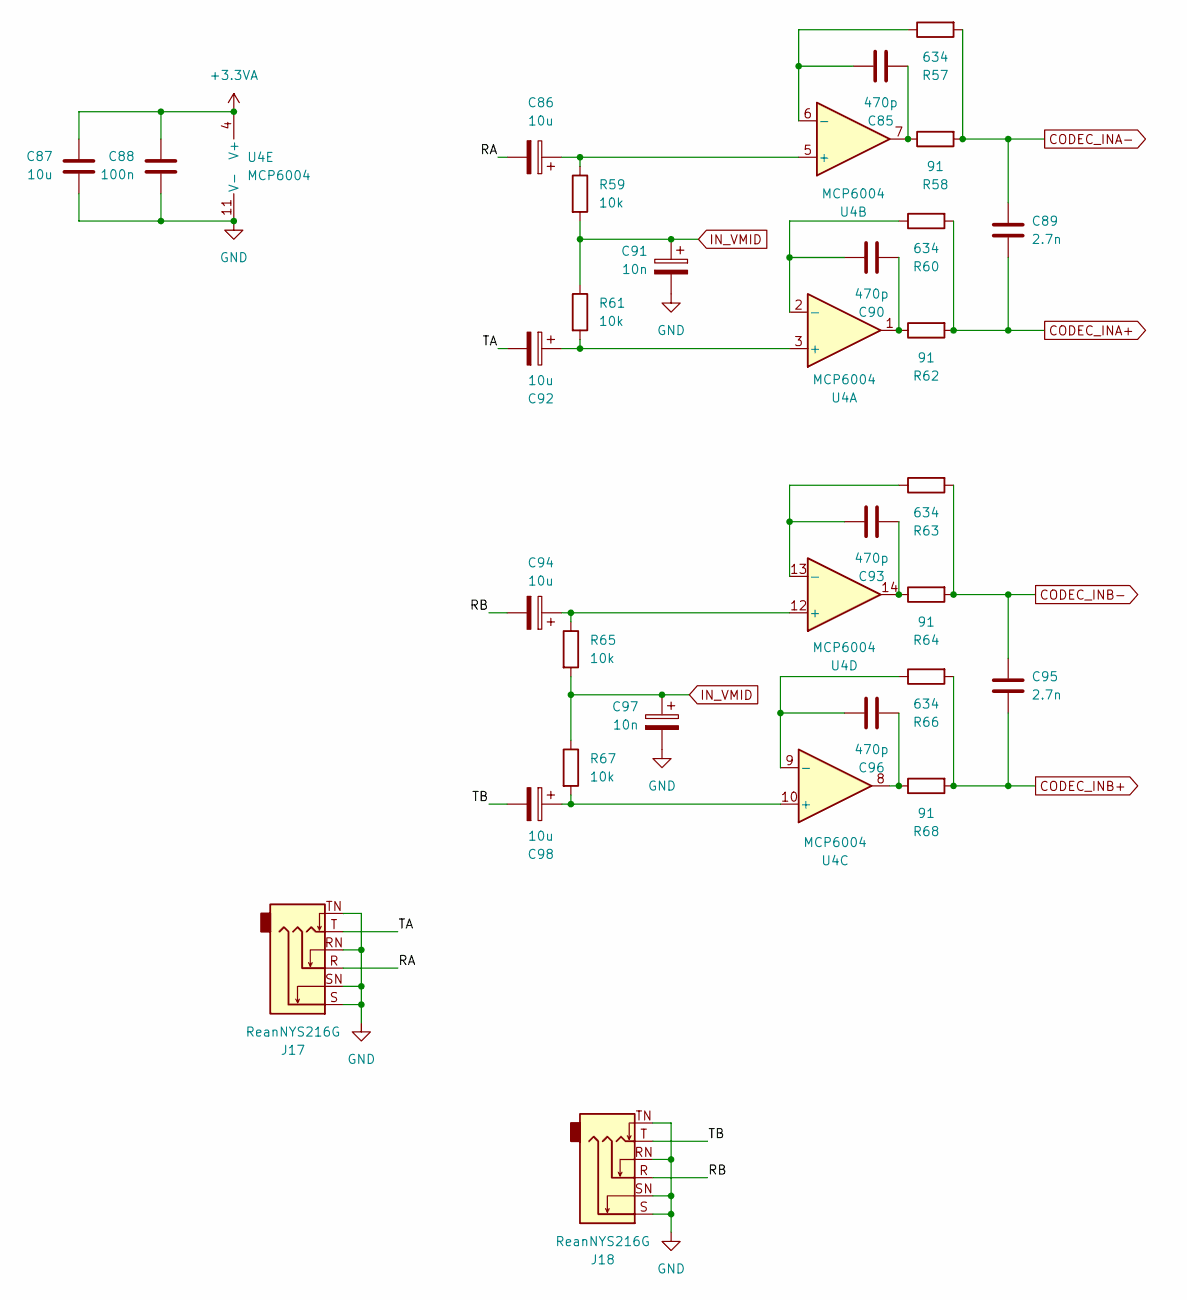
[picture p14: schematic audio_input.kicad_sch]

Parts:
C85, C90, C93, C96: 470p; C_0603_1608Metric_Pad1.08x0.95mm_HandSolder
C86, C87, C92, C94, C98: 10u; C_0805_2012Metric_Pad1.18x1.45mm_HandSolder
C88: 100n; C_0603_1608Metric_Pad1.08x0.95mm_HandSolder
C89, C95: 2.7n; C_0603_1608Metric_Pad1.08x0.95mm_HandSolder
C91, C97: 10n; C_0603_1608Metric_Pad1.08x0.95mm_HandSolder
J17, J18: ReanNYS216G; NYS-216G
R57, R60, R63, R66: 634; R_0603_1608Metric_Pad0.98x0.95mm_HandSolder
R58, R62, R64, R68: 91; R_0603_1608Metric_Pad0.98x0.95mm_HandSolder
R59, R61, R65, R67: 10k; R_0603_1608Metric_Pad0.98x0.95mm_HandSolder
U4: MCP6004; TSSOP-14_4.4x5mm_P0.65mm

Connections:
+3.3VA: C87.1, C88.1, U4.4 (V+); also elsewhere on the board
/Codec and audio IO/Audio input/RA: C86.2, J17.R
/Codec and audio IO/Audio input/RB: C94.2, J18.R
/Codec and audio IO/Audio input/TA: C92.2, J17.T
/Codec and audio IO/Audio input/TB: C98.2, J18.T
CODEC_INA+: C89.2, R60.2, R62.2; also elsewhere on the board
CODEC_INA-: C89.1, R57.2, R58.2; also elsewhere on the board
CODEC_INB+: C95.2, R66.2, R68.2; also elsewhere on the board
CODEC_INB-: C95.1, R63.2, R64.2; also elsewhere on the board
GND: C87.2, C88.2, C91.2, C97.2, J17.RN, J17.S, J17.SN, J17.TN, J18.RN, J18.S, J18.SN, J18.TN, U4.11 (V-); also elsewhere on the board
IN_VMID: C91.1, C97.1, R59.2, R61.1, R65.2, R67.1; also elsewhere on the board
unnamed: C85.1, R58.1, U4.7
unnamed: C90.1, R62.1, U4.1
unnamed: C93.1, R64.1, U4.14
unnamed: C96.1, R68.1, U4.8
unnamed: C92.1, R61.2, U4.3 (+)
unnamed: C90.2, R60.1, U4.2 (-)
unnamed: C86.1, R59.1, U4.5 (+)
unnamed: C85.2, R57.1, U4.6 (-)
unnamed: C98.1, R67.2, U4.10 (+)
unnamed: C96.2, R66.1, U4.9 (-)
unnamed: C94.1, R65.1, U4.12 (+)
unnamed: C93.2, R63.1, U4.13 (-)

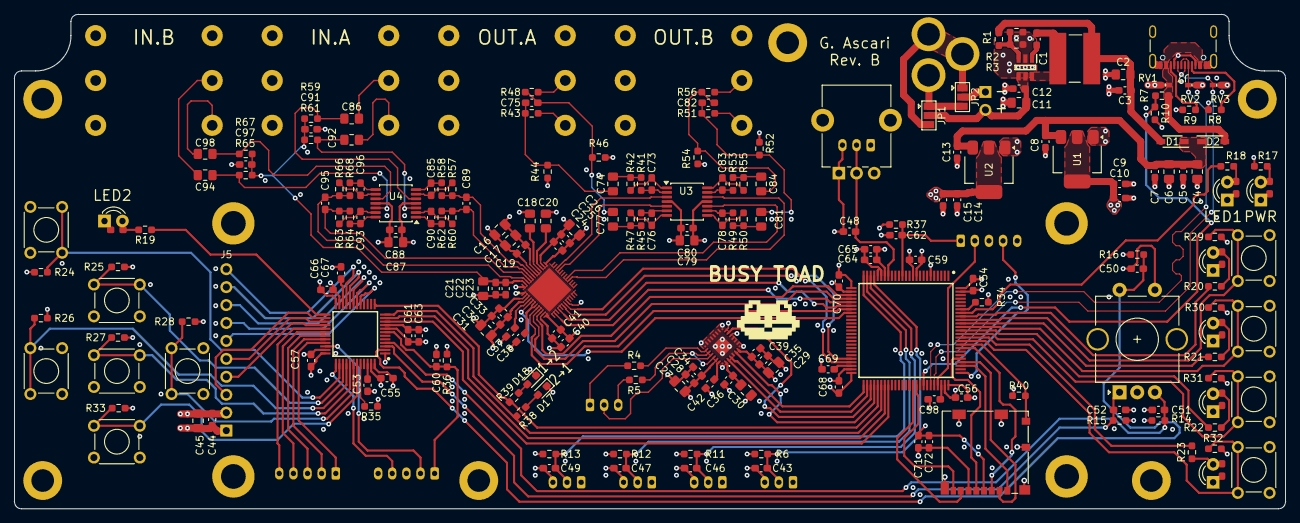
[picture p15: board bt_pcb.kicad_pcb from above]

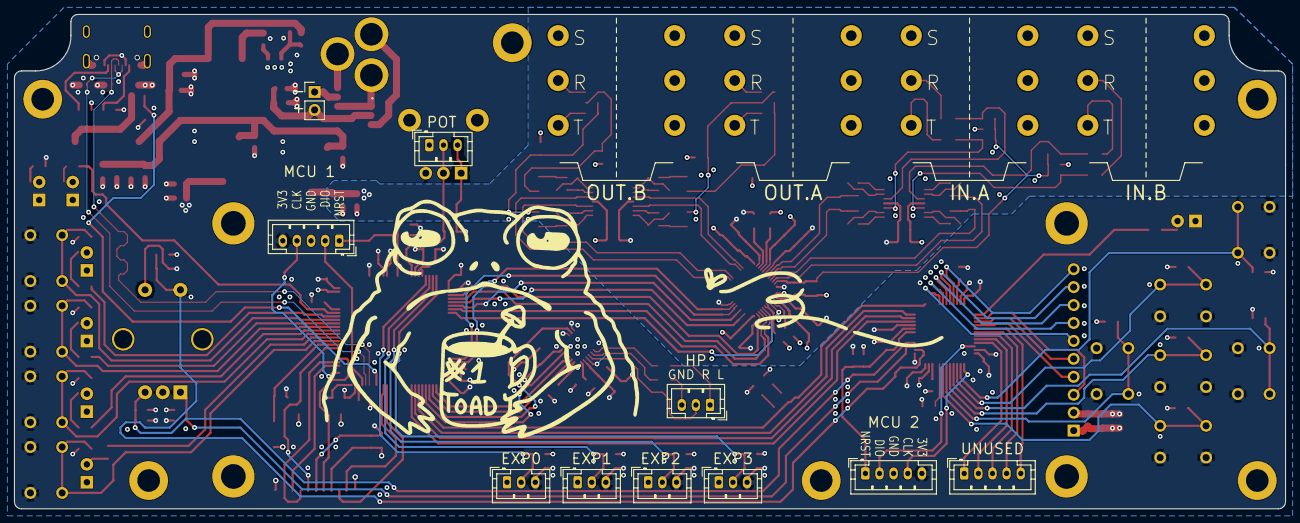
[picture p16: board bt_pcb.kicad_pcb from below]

Board: 4 copper layers, 180.0 x 70.0 mm, 235 parts (15 on the bottom side), 154 nets.

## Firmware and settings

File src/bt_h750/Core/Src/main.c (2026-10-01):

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
/* Includes ------------------------------------------------------------------*/
#include "main.h"

/* USER CODE BEGIN Includes */
#include <string.h>

/* USER CODE END Includes */

/* USER CODE BEGIN PD */
#define HP_BUFFER_SIZE 512
#define HP_BLOCK_SIZE (HP_BUFFER_SIZE / 2)
#define HP_SR_F 48950.0f
#define HP_SR_I 48950

#define CODEC_BUFFER_SIZE 512
#define CODEC_BLOCK_SIZE (CODEC_BUFFER_SIZE / 2)
#define CODEC_SR_F 48950.0f
#define CODEC_SR_I 48950

#define FLOAT_TO_INT16 (32768.0f)
#define INT16_TO_FLOAT (1.0f / 32768.0f)
#define FLOAT_TO_INT32 (2147483648.0f)
#define INT32_TO_FLOAT (1.0f / 2147483648.0f)

#define PI 3.14159265f
#define STARTUP_RAMP_MS 100U
#define STARTUP_RAMP_SAMPLES ((uint32_t)(HP_SR_F * STARTUP_RAMP_MS / 1000.0f))

/* USER CODE END PD */

ADC_HandleTypeDef hadc1;

I2C_HandleTypeDef hi2c2;

I2S_HandleTypeDef hi2s1;
I2S_HandleTypeDef hi2s2;
DMA_HandleTypeDef hdma_spi1_rx;
DMA_HandleTypeDef hdma_spi1_tx;
DMA_HandleTypeDef hdma_spi2_tx;

SD_HandleTypeDef hsd1;

UART_HandleTypeDef huart3;

PCD_HandleTypeDef hpcd_USB_OTG_FS;

/* USER CODE BEGIN PV */
CS4282P_HandleTypeDef hcs4282p;

/* DMA1 cannot access DTCMRAM, so this buffer must live in AXI SRAM (see .dma_buffer in the linker script) */

/* TO PUT ON LINE ~233. DMA-accessible buffers: DTCMRAM is not reachable by DMA1/DMA2 on STM32H7, so place these in AXI SRAM instead */
/*.dma_buffer (NOLOAD) :
{
  . = ALIGN(4);
  *(.dma_buffer)
  *(.dma_buffer*)
  . = ALIGN(4);
} >RAM*/

__attribute__((section(".dma_buffer"))) int32_t hpDacData[HP_BUFFER_SIZE];
static volatile int32_t* hpOutBuf = &hpDacData[0];
uint8_t hpDataReady = 0;

__attribute__((section(".dma_buffer"))) int32_t codecDacData[CODEC_BUFFER_SIZE];
static volatile int32_t* codecOutBuf = &codecDacData[0];
uint8_t codecOutDataReady = 0;

/* USER CODE END PV */

void SystemClock_Config(void);
void PeriphCommonClock_Config(void);
static void MPU_Config(void);
static void MX_GPIO_Init(void);
static void MX_DMA_Init(void);
static void MX_ADC1_Init(void);
static void MX_USB_OTG_FS_PCD_Init(void);
static void MX_I2C2_Init(void);
static void MX_I2S1_Init(void);
static void MX_I2S2_Init(void);
static void MX_SDMMC1_SD_Init(void);
static void MX_USART3_UART_Init(void);
/* USER CODE BEGIN PFP */
// https://youtu.be/zlGSxZGwj-E?t=823

/* USER CODE END PFP */

/* USER CODE BEGIN 0 */
void HAL_I2S_TxCpltCallback(I2S_HandleTypeDef *hi2s) {
  if (hi2s == &hi2s2) {
    hpOutBuf = &hpDacData[HP_BLOCK_SIZE];
    hpDataReady = 1;
  } else if (hi2s == &hi2s1) {
    codecOutBuf = &codecDacData[CODEC_BLOCK_SIZE];
    codecOutDataReady = 1;
  }
}

void HAL_I2S_TxHalfCpltCallback(I2S_HandleTypeDef *hi2s) {
  if (hi2s == &hi2s2) {
    hpOutBuf = &hpDacData[0];
    hpDataReady = 1;
  } else if (hi2s == &hi2s1) {
    codecOutBuf = &codecDacData[0];
    codecOutDataReady = 1;
  }
}

void HAL_I2S_RxCpltCallback(I2S_HandleTypeDef *hi2s) {
  if (hi2s == &hi2s1) {
    // something
  }
}

void HAL_I2S_RxHalfCpltCallback(I2S_HandleTypeDef *hi2s) {
  if (hi2s == &hi2s1) {
    // something
  }
}

void HAL_I2S_ErrorCallback(I2S_HandleTypeDef *hi2s) {
  if (hi2s->ErrorCode != HAL_I2S_ERROR_NONE) {
    // Handle I2S error
  }
}

void processHpData() {
  static uint32_t sample = 0;
  static float gain, sine, leftOut, rightOut, ramp;
  for (uint32_t i = 0; i < HP_BLOCK_SIZE; i += 2) {
    ramp = sample < STARTUP_RAMP_SAMPLES
      ? (float)sample / (float)STARTUP_RAMP_SAMPLES
      : 1.0f;
    gain = 0.02f;
    sine = sinf(2.f * PI * 440.f * (float)sample / HP_SR_F) * gain;
    leftOut = sine * ramp;
    rightOut = sine * ramp;
    hpOutBuf[i] = (int32_t)(FLOAT_TO_INT32 * leftOut);
    hpOutBuf[i+1] = (int32_t)(FLOAT_TO_INT32 * rightOut);
    sample++;
  }
  sample %= HP_SR_I;
}

/* USER CODE END 0 */

/**
  * @brief  The application entry point.
  * @retval int
  */
int main(void)
{

  /* MPU Configuration--------------------------------------------------------*/
  MPU_Config();

  /* MCU Configuration--------------------------------------------------------*/

  /* Reset of all peripherals, Initializes the Flash interface and the Systick. */
  HAL_Init();

  /* Configure the system clock */
  SystemClock_Config();

  /* Configure the peripherals common clocks */
  PeriphCommonClock_Config();

  /* Initialize all configured peripherals */
  MX_GPIO_Init();
  MX_DMA_Init();
  MX_ADC1_Init();
  MX_USB_OTG_FS_PCD_Init();
  MX_I2C2_Init();
  MX_I2S1_Init();
  MX_I2S2_Init();
  MX_SDMMC1_SD_Init();
  MX_USART3_UART_Init();
  /* USER CODE BEGIN 2 */
  memset(hpDacData, 0, sizeof(hpDacData));
  memset(codecDacData, 0, sizeof(codecDacData));
  HAL_SD_CardInfoTypeDef CardInfo;
  if (HAL_SD_GetCardInfo(&hsd1, &CardInfo) == HAL_OK)
  {
    /* Card info successfully retrieved */
  }

  CS4282P_Init(&hcs4282p, &hi2c2, &hi2s1, CODEC_RESET_GPIO_Port, CODEC_RESET_Pin);

  HAL_I2S_Transmit_DMA(&hi2s2, (uint16_t*)hpDacData,HP_BUFFER_SIZE);

  uint32_t tick = 0;
  /* USER CODE END 2 */

  /* Infinite loop */
  /* USER CODE BEGIN WHILE */
  while (1)
  {
    /* USER CODE END WHILE */

    /* USER CODE BEGIN 3 */
    tick = HAL_GetTick();
    if (tick % 1000 > 500 && tick % 4 == 0) {
      HAL_GPIO_WritePin(GPIOB, LED_A_Pin | LED_B_Pin, GPIO_PIN_SET);
      HAL_GPIO_WritePin(GPIOD, LED_C_Pin | LED_D_Pin, GPIO_PIN_SET);
    } else {
      HAL_GPIO_WritePin(GPIOB, LED_A_Pin | LED_B_Pin, GPIO_PIN_RESET);
      HAL_GPIO_WritePin(GPIOD, LED_C_Pin | LED_D_Pin, GPIO_PIN_RESET);
    }

    if (hpDataReady) {
      processHpData();
      hpDataReady = 0;
    }

    /*sd_detect = HAL_GPIO_ReadPin(SD_DETECT_GPIO_Port, SD_DETECT_Pin);
    if (sd_detect == GPIO_PIN_RESET) {
      HAL_SD_WriteBlocks(&hsd1, pData, BlockAdd, NumberOfBlocks, Timeout);
    }

    pData[0]++; // Example modification to the data buffer

    if (sd_detect == GPIO_PIN_RESET) {
      HAL_SD_ReadBlocks(&hsd1, pData, BlockAdd, NumberOfBlocks, Timeout);
    }*/


    //HAL_GPIO_TogglePin(GPIOB, LED_RD_Pin | LED_A_Pin | LED_B_Pin);
    //HAL_GPIO_TogglePin(GPIOD, LED_C_Pin | LED_D_Pin);
    //HAL_Delay(500);
  }
  /* USER CODE END 3 */
}

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
 /* MPU Configuration */

void MPU_Config(void)
{
  MPU_Region_InitTypeDef MPU_InitStruct = {0};

  /* Disables the MPU */
  HAL_MPU_Disable();

  /** Initializes and configures the Region and the memory to be protected
  */
  MPU_InitStruct.Enable = MPU_REGION_ENABLE;
  MPU_InitStruct.Number = MPU_REGION_NUMBER0;
  MPU_InitStruct.BaseAddress = 0x0;
  MPU_InitStruct.Size = MPU_REGION_SIZE_4GB;
  MPU_InitStruct.SubRegionDisable = 0x87;
  MPU_InitStruct.TypeExtField = MPU_TEX_LEVEL0;
  MPU_InitStruct.AccessPermission = MPU_REGION_NO_ACCESS;
  MPU_InitStruct.DisableExec = MPU_INSTRUCTION_ACCESS_DISABLE;
  MPU_InitStruct.IsShareable = MPU_ACCESS_SHAREABLE;
  MPU_InitStruct.IsCacheable = MPU_ACCESS_NOT_CACHEABLE;
  MPU_InitStruct.IsBufferable = MPU_ACCESS_NOT_BUFFERABLE;

  HAL_MPU_ConfigRegion(&MPU_InitStruct);
  /* Enables the MPU */
  HAL_MPU_Enable(MPU_PRIVILEGED_DEFAULT);

}

/**
  * @brief  This function is executed in case of error occurrence.
  * @retval None
  */
void Error_Handler(void)
{
  /* USER CODE BEGIN Error_Handler_Debug */
  /* User can add his own implementation to report the HAL error return state */
  __disable_irq();
  while (1)
  {
  }
  /* USER CODE END Error_Handler_Debug */
}
#ifdef USE_FULL_ASSERT
/**
  * @brief  Reports the name of the source file and the source line number
  *         where the assert_param error has occurred.
  * @param  file: pointer to the source file name
  * @param  line: assert_param error line source number
  * @retval None
  */
void assert_failed(uint8_t *file, uint32_t line)
{
  /* USER CODE BEGIN 6 */
  /* User can add his own implementation to report the file name and line number,
     ex: printf("Wrong parameters value: file %s on line %d\r\n", file, line) */
  /* USER CODE END 6 */
}
#endif /* USE_FULL_ASSERT */

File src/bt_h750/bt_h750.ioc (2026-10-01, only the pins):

Mcu.UserName=STM32H750VBTx
PA0.GPIO_Label=EXP_0
PA0.Signal=ADC1_INP16
PA1.GPIO_Label=EXP_1
PA1.Signal=ADC1_INP17
PA10.GPIO_Label=X
PA10.Signal=GPIO_Analog
PA11.Signal=USB_OTG_FS_DM
PA12.Signal=USB_OTG_FS_DP
PA2.GPIO_Label=EXP_2
PA2.Signal=ADCx_INP14
PA3.GPIO_Label=EXP_3
PA3.Signal=ADCx_INP15
PA4.GPIO_Label=CODEC_I2S_WS
PA4.Signal=I2S1_WS
PA5.GPIO_Label=CODEC_I2S_CK
PA5.Signal=I2S1_CK
PA6.GPIO_Label=CODEC_I2S_SDI
PA6.Signal=I2S1_SDI
PA7.GPIO_Label=CODEC_I2S_SDO
PA7.Signal=I2S1_SDO
PA8.GPIO_Label=X
PA8.Signal=GPIO_Analog
PA9.Signal=USB_OTG_FS_VBUS
PB0.GPIO_Label=X
PB0.Signal=GPIO_Analog
PB1.GPIO_Label=X
PB1.Signal=GPIO_Analog
PB10.GPIO_Label=CODEC_I2C_SCL
PB10.Signal=I2C2_SCL
PB11.GPIO_Label=CODEC_I2C_SDA
PB11.Signal=I2C2_SDA
PB12.GPIO_Label=HPDAC_I2S_WS
PB12.Signal=I2S2_WS
PB13.GPIO_Label=HPDAC_I2S_BCK
PB13.Signal=I2S2_CK
PB14.GPIO_Label=HPDAC_I2S_SDI
PB14.Signal=I2S2_SDI
PB15.GPIO_Label=HPDAC_I2S_SDO
PB15.Signal=I2S2_SDO
PB2.GPIO_Label=X
PB2.Signal=GPIO_Analog
PB5.GPIO_Label=BTN_A
PB5.Signal=GPIO_Input
PB6.GPIO_Label=LED_A
PB6.Signal=GPIO_Output
PB7.GPIO_Label=LED_RD
PB7.Signal=GPIO_Output
PB8.GPIO_Label=X
PB8.Signal=GPIO_Analog
PB9.GPIO_Label=X
PB9.Signal=GPIO_Analog
PC0.GPIO_Label=X
PC0.Signal=GPIO_Analog
PC1.GPIO_Label=X
PC1.Signal=GPIO_Analog
PC10.GPIO_Label=SD_D2
PC10.Signal=SDMMC1_D2
PC11.GPIO_Label=SD_D3
PC11.Signal=SDMMC1_D3
PC12.GPIO_Label=SD_CK
PC12.Signal=SDMMC1_CK
PC13.GPIO_Label=X
PC13.Signal=GPIO_Analog
PC2_C.GPIO_Label=X
PC2_C.Signal=GPIO_Analog
PC3_C.GPIO_Label=POT_0
PC3_C.Signal=SharedAnalog_PC3
PC4.GPIO_Label=CODEC_I2S_MCK
PC4.Signal=I2S1_MCK
PC5.GPIO_Label=CODEC_RESET
PC5.Signal=GPIO_Output
PC6.GPIO_Label=X
PC6.Signal=GPIO_Analog
PC7.GPIO_Label=X
PC7.Signal=GPIO_Analog
PC8.GPIO_Label=SD_D0
PC8.Signal=SDMMC1_D0
PC9.GPIO_Label=SD_D1
PC9.Signal=SDMMC1_D1
PD0.GPIO_Label=X
PD0.Signal=GPIO_Analog
PD1.GPIO_Label=X
PD1.Signal=GPIO_Analog
PD10.GPIO_Label=AUX_OUTPUT
PD10.Signal=GPIO_Output
PD11.GPIO_Label=AUX_INPUT
PD11.Signal=GPIO_Input
PD12.GPIO_Label=X
PD12.Signal=GPIO_Analog
PD13.GPIO_Label=X
PD13.Signal=GPIO_Analog
PD14.GPIO_Label=X
PD14.Signal=GPIO_Analog
PD15.GPIO_Label=X
PD15.Signal=GPIO_Analog
PD2.GPIO_Label=SD_CMD
PD2.Signal=SDMMC1_CMD
PD3.GPIO_Label=SD_DETECT
PD3.Signal=GPIO_Input
PD4.GPIO_Label=BTN_D
PD4.Signal=GPIO_Input
PD5.GPIO_Label=LED_D
PD5.Signal=GPIO_Output
PD6.GPIO_Label=BTN_C
PD6.Signal=GPIO_Input
PD7.GPIO_Label=LED_C
PD7.Signal=GPIO_Output
PD8.GPIO_Label=USART_TX
PD8.Signal=USART3_TX
PD9.GPIO_Label=USART_RX
PD9.Signal=USART3_RX
PE0.GPIO_Label=X
PE0.Signal=GPIO_Analog
PE1.GPIO_Label=X
PE1.Signal=GPIO_Analog
PE10.GPIO_Label=X
PE10.Signal=GPIO_Analog
PE11.GPIO_Label=X
PE11.Signal=GPIO_Analog
PE12.GPIO_Label=X
PE12.Signal=GPIO_Analog
PE13.GPIO_Label=X
PE13.Signal=GPIO_Analog
PE14.GPIO_Label=X
PE14.Signal=GPIO_Analog
PE15.GPIO_Label=X
PE15.Signal=GPIO_Analog
PE2.GPIO_Label=X
PE2.Signal=GPIO_Analog
PE3.GPIO_Label=X
PE3.Signal=GPIO_Analog
PE4.GPIO_Label=X
PE4.Signal=GPIO_Analog
PE5.GPIO_Label=X
PE5.Signal=GPIO_Analog
PE6.GPIO_Label=X
PE6.Signal=GPIO_Analog
PE7.GPIO_Label=X
PE7.Signal=GPIO_Analog
PE8.GPIO_Label=X
PE8.Signal=GPIO_Analog
PE9.GPIO_Label=X
PE9.Signal=GPIO_Analog

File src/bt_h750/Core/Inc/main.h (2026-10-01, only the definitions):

#define X_Pin GPIO_PIN_2
#define X_GPIO_Port GPIOE
#define XE3_Pin GPIO_PIN_3
#define XE3_GPIO_Port GPIOE
#define XE4_Pin GPIO_PIN_4
#define XE4_GPIO_Port GPIOE
#define XE5_Pin GPIO_PIN_5
#define XE5_GPIO_Port GPIOE
#define XE6_Pin GPIO_PIN_6
#define XE6_GPIO_Port GPIOE
#define XC13_Pin GPIO_PIN_13
#define XC13_GPIO_Port GPIOC
#define XC14_Pin GPIO_PIN_14
#define XC14_GPIO_Port GPIOC
#define XC15_Pin GPIO_PIN_15
#define XC15_GPIO_Port GPIOC
#define XH0_Pin GPIO_PIN_0
#define XH0_GPIO_Port GPIOH
#define XH1_Pin GPIO_PIN_1
#define XH1_GPIO_Port GPIOH
#define XC0_Pin GPIO_PIN_0
#define XC0_GPIO_Port GPIOC
#define XC1_Pin GPIO_PIN_1
#define XC1_GPIO_Port GPIOC
#define XC2_Pin GPIO_PIN_2
#define XC2_GPIO_Port GPIOC
#define POT_0_Pin GPIO_PIN_3
#define POT_0_GPIO_Port GPIOC
#define EXP_0_Pin GPIO_PIN_0
#define EXP_0_GPIO_Port GPIOA
#define EXP_1_Pin GPIO_PIN_1
#define EXP_1_GPIO_Port GPIOA
#define EXP_2_Pin GPIO_PIN_2
#define EXP_2_GPIO_Port GPIOA
#define EXP_3_Pin GPIO_PIN_3
#define EXP_3_GPIO_Port GPIOA
#define CODEC_I2S_WS_Pin GPIO_PIN_4
#define CODEC_I2S_WS_GPIO_Port GPIOA
#define CODEC_I2S_CK_Pin GPIO_PIN_5
#define CODEC_I2S_CK_GPIO_Port GPIOA
#define CODEC_I2S_SDI_Pin GPIO_PIN_6
#define CODEC_I2S_SDI_GPIO_Port GPIOA
#define CODEC_I2S_SDO_Pin GPIO_PIN_7
#define CODEC_I2S_SDO_GPIO_Port GPIOA
#define CODEC_I2S_MCK_Pin GPIO_PIN_4
#define CODEC_I2S_MCK_GPIO_Port GPIOC
#define CODEC_RESET_Pin GPIO_PIN_5
#define CODEC_RESET_GPIO_Port GPIOC
#define XB0_Pin GPIO_PIN_0
#define XB0_GPIO_Port GPIOB
#define XB1_Pin GPIO_PIN_1
#define XB1_GPIO_Port GPIOB
#define XB2_Pin GPIO_PIN_2
#define XB2_GPIO_Port GPIOB
#define XE7_Pin GPIO_PIN_7
#define XE7_GPIO_Port GPIOE
#define XE8_Pin GPIO_PIN_8
#define XE8_GPIO_Port GPIOE
#define XE9_Pin GPIO_PIN_9
#define XE9_GPIO_Port GPIOE
#define XE10_Pin GPIO_PIN_10
#define XE10_GPIO_Port GPIOE
#define XE11_Pin GPIO_PIN_11
#define XE11_GPIO_Port GPIOE
#define XE12_Pin GPIO_PIN_12
#define XE12_GPIO_Port GPIOE
#define XE13_Pin GPIO_PIN_13
#define XE13_GPIO_Port GPIOE
#define XE14_Pin GPIO_PIN_14
#define XE14_GPIO_Port GPIOE
#define XE15_Pin GPIO_PIN_15
#define XE15_GPIO_Port GPIOE
#define CODEC_I2C_SCL_Pin GPIO_PIN_10
#define CODEC_I2C_SCL_GPIO_Port GPIOB
#define CODEC_I2C_SDA_Pin GPIO_PIN_11
#define CODEC_I2C_SDA_GPIO_Port GPIOB
#define HPDAC_I2S_WS_Pin GPIO_PIN_12
#define HPDAC_I2S_WS_GPIO_Port GPIOB
#define HPDAC_I2S_BCK_Pin GPIO_PIN_13
#define HPDAC_I2S_BCK_GPIO_Port GPIOB
#define HPDAC_I2S_SDI_Pin GPIO_PIN_14
#define HPDAC_I2S_SDI_GPIO_Port GPIOB
#define HPDAC_I2S_SDO_Pin GPIO_PIN_15
#define HPDAC_I2S_SDO_GPIO_Port GPIOB
#define USART_TX_Pin GPIO_PIN_8
#define USART_TX_GPIO_Port GPIOD
#define USART_RX_Pin GPIO_PIN_9
#define USART_RX_GPIO_Port GPIOD
#define AUX_OUTPUT_Pin GPIO_PIN_10
#define AUX_OUTPUT_GPIO_Port GPIOD
#define AUX_INPUT_Pin GPIO_PIN_11
#define AUX_INPUT_GPIO_Port GPIOD
#define XD12_Pin GPIO_PIN_12
#define XD12_GPIO_Port GPIOD
#define XD13_Pin GPIO_PIN_13
#define XD13_GPIO_Port GPIOD
#define XD14_Pin GPIO_PIN_14
#define XD14_GPIO_Port GPIOD
#define XD15_Pin GPIO_PIN_15
#define XD15_GPIO_Port GPIOD
#define XC6_Pin GPIO_PIN_6
#define XC6_GPIO_Port GPIOC
#define XC7_Pin GPIO_PIN_7
#define XC7_GPIO_Port GPIOC
#define SD_D0_Pin GPIO_PIN_8
#define SD_D0_GPIO_Port GPIOC
#define SD_D1_Pin GPIO_PIN_9
#define SD_D1_GPIO_Port GPIOC
#define XA8_Pin GPIO_PIN_8
#define XA8_GPIO_Port GPIOA
#define XA10_Pin GPIO_PIN_10
#define XA10_GPIO_Port GPIOA
#define XA15_Pin GPIO_PIN_15
#define XA15_GPIO_Port GPIOA
#define SD_D2_Pin GPIO_PIN_10
#define SD_D2_GPIO_Port GPIOC
#define SD_D3_Pin GPIO_PIN_11
#define SD_D3_GPIO_Port GPIOC
#define SD_CK_Pin GPIO_PIN_12
#define SD_CK_GPIO_Port GPIOC
#define XD0_Pin GPIO_PIN_0
#define XD0_GPIO_Port GPIOD
#define XD1_Pin GPIO_PIN_1
#define XD1_GPIO_Port GPIOD
#define SD_CMD_Pin GPIO_PIN_2
#define SD_CMD_GPIO_Port GPIOD
#define SD_DETECT_Pin GPIO_PIN_3
#define SD_DETECT_GPIO_Port GPIOD
#define BTN_D_Pin GPIO_PIN_4
#define BTN_D_GPIO_Port GPIOD
#define LED_D_Pin GPIO_PIN_5
#define LED_D_GPIO_Port GPIOD
#define BTN_C_Pin GPIO_PIN_6
#define BTN_C_GPIO_Port GPIOD
#define LED_C_Pin GPIO_PIN_7
#define LED_C_GPIO_Port GPIOD
#define BTN_B_Pin GPIO_PIN_3
#define BTN_B_GPIO_Port GPIOB
#define LED_B_Pin GPIO_PIN_4
#define LED_B_GPIO_Port GPIOB
#define BTN_A_Pin GPIO_PIN_5
#define BTN_A_GPIO_Port GPIOB
#define LED_A_Pin GPIO_PIN_6
#define LED_A_GPIO_Port GPIOB
#define LED_RD_Pin GPIO_PIN_7
#define LED_RD_GPIO_Port GPIOB
#define XB8_Pin GPIO_PIN_8
#define XB8_GPIO_Port GPIOB
#define XB9_Pin GPIO_PIN_9
#define XB9_GPIO_Port GPIOB
#define XE0_Pin GPIO_PIN_0
#define XE0_GPIO_Port GPIOE
#define XE1_Pin GPIO_PIN_1
#define XE1_GPIO_Port GPIOE

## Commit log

2024-02-05 progress on audio pcb
    [bt_pcb.kicad_sch, codec_and_audio.kicad_sch]
2024-02-08 progress on understanding audio schematics
    [bt_pcb.kicad_sch, codec_and_audio.kicad_sch]
2024-02-13 couple of things
    [bt_pcb.kicad_sch, codec_and_audio.kicad_sch, power_supply.kicad_sch]
2024-02-13 progress on audio in
    [codec_and_audio.kicad_sch]
2024-02-14 progress on audio
    [codec_and_audio.kicad_sch]
2024-10-14 progress on shcematics
    [bt_pcb.kicad_sch, codec_and_audio.kicad_sch, power_supply.kicad_sch]
2024-10-16 some invenstigation on the codec circuitry
2024-10-16 i forgot this
    [codec_and_audio.kicad_sch]
2024-10-27 some more pages for the schematic
    [bt_pcb.kicad_sch, codec_and_audio.kicad_sch, input_a.kicad_sch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]
2024-11-03 big progress!
    [bt_pcb.kicad_sch, codec_and_audio.kicad_sch, input_a.kicad_sch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]
2024-11-19 making up my mind on the heaphones
    [bt_pcb.kicad_sch, codec_and_audio.kicad_sch, input_a.kicad_sch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]
2024-11-21 progress on hp
    [bt_pcb.kicad_sch, codec_and_audio.kicad_sch, output_a.kicad_sch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]
2024-11-30 a lot of audio finished, now onto ui
    [audio_input.kicad_sch, audio_output.kicad_sch, bt_pcb.kicad_sch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]
2024-12-05 a lot of work! almost ready for rev
    [audio_input.kicad_sch, audio_output.kicad_sch, bt_pcb.kicad_sch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]
2024-12-06 schematic finished, now under revision
    [bt_pcb.kicad_sch, usb_interface.kicad_sch, user_interface.kicad_sch]
2024-12-18 starting the revision from ed
    [audio_input.kicad_sch, audio_output.kicad_sch, bt_pcb.csv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]
2025-03-25 reprising work
    [bt_pcb.kicad_sch]
2025-03-29 started development on power pcb
    [audio_input.kicad_sch, audio_output.kicad_sch, bt_pcb.csv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]
2025-10-18 ditching power pcb, new codec
    [audio_input.kicad_sch, audio_output.kicad_sch, bt_pcb.kicad_sch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]
2025-10-20 complete makeover of power supply
    [bt_pcb.kicad_sch, codec_and_audio.kicad_sch, power_supply.kicad_sch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]
2025-10-28 big progress, now revising error and warnings
    [audio_input.kicad_sch, audio_output.kicad_sch, codec_and_audio.kicad_sch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]
2025-11-02 solving some erc warnings and errors
    [audio_input.kicad_sch, audio_output.kicad_sch, bt_pcb.kicad_sch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]
2025-11-09 schematic in theory finished
    [audio_input.kicad_sch, audio_output.kicad_sch, codec_and_audio.kicad_sch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]
2025-11-09 finished for real, now onto review
    [mcus.kicad_sch]
2025-11-09 pcb started
    [audio_input.kicad_sch, audio_output.kicad_sch, bt_pcb.kicad_pcb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]
2025-11-12 pcb with some schematic tuning
    [audio_input.kicad_sch, audio_output.kicad_sch, bt_pcb.kicad_pcb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]
2025-11-12 progress on pcb
2025-11-17 pcb now under revision
    [audio_input.kicad_sch, audio_output.kicad_sch, bt_pcb.kicad_pcb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]
2025-11-18 continuing review
    [bt_pcb.kicad_pcb, bt_pcb.kicad_sch]
2025-11-18 removal of old files
    [power_pcb.kicad_pcb, power_pcb.kicad_sch, power_supply.kicad_sch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]
2025-12-01 first notes
    [audio_input.kicad_sch, audio_output.kicad_sch, bt_pcb.kicad_pcb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]
2025-12-12 first reiteration
    [bt_pcb.kicad_pcb, codec_and_audio.kicad_sch, mcus.kicad_sch]
2026-01-11 doing pcb from scratch again
    [audio_input.kicad_sch, audio_output.kicad_sch, bt_pcb.kicad_pcb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]
2026-01-11 layed components down
    [bt_pcb.kicad_pcb, bt_pcb.kicad_sch]
2026-01-22 routing stuff
    [bt_pcb.kicad_pcb, mcus.kicad_sch]
2026-01-30 almost there
    [bt_pcb.kicad_pcb]
2026-02-10 redo of power supply
    [audio_input.kicad_sch, audio_output.kicad_sch, bt_pcb.kicad_pcb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]
2026-02-12 made a bom
    [audio_input.kicad_sch, audio_output.kicad_sch, bt_pcb.csv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]
2026-02-12 updated and pretty bom
    [bom.csv, bom.ods, bt_pcb.kicad_sch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]
2026-02-18 seeing the end of the tunnel
    [audio_input.kicad_sch, audio_output.kicad_sch, bom.csv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]
2026-02-19 font draft and picture on pcb
    [bt_pcb.kicad_pcb]
2026-02-21 order of rev a eheh
    [bt_pcb.kicad_pcb, busy_toad_rev_a_bom.csv, busy_toad_rev_a_designators.csv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]
2026-04-08 schematics svgs
2026-05-09 schematic rev b finish?
    [audio_input.kicad_sch, audio_output.kicad_sch, bt_pcb.kicad_pcb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]
2026-05-11 just need to fix usb
    [audio_input.kicad_sch, audio_output.kicad_sch, bt_pcb.kicad_pcb]
2026-05-12 usb fatta!
    [bt_pcb.kicad_pcb]
2026-05-14 rev b likely finished
    [bt_pcb.csv, bt_pcb.kicad_pcb, codec_and_audio.kicad_sch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]
2026-05-15 sd card is the way probably :(
    [bt_pcb.kicad_pcb, mcus.kicad_sch, power_supply.kicad_sch]
2026-05-15 sd kind of in
    [audio_input.kicad_sch, audio_output.kicad_sch, bt_pcb.kicad_pcb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]
2026-05-17 wired! now just checking
    [bt_pcb.kicad_pcb]
2026-05-18 led1 now not under the display
    [bt_pcb.kicad_pcb]
2026-05-23 fixed usb impedance
    [bt_pcb.kicad_pcb]
2026-05-25 bom bom bom
    [bom.csv, bom.ods, bt_pcb.csv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]
2026-06-06 reb b finished
    [audio_input.kicad_sch, audio_output.kicad_sch, bom.csv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]
2026-06-06 rev b really finished
    [bt_pcb.kicad_pcb, busy_toad_rev_b_bom.csv, busy_toad_rev_b_designators.csv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]
2026-09-26 hp dac working
    [bt_pcb.kicad_sch]
2026-10-01 i2c for codec works

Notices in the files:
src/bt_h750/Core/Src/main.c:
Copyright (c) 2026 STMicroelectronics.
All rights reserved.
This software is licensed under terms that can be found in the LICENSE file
